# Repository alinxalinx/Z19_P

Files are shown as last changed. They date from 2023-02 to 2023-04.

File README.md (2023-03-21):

# Xilinx Zynq Ultrascale+ MPSoC Series Development Board Z19_P
## Introduction to Development Board
The entire structure of the development board is designed based on our consistent core board+extension board pattern. Core board and expansion board
High speed inter board connectors are used for connection.
The core board is mainly composed of a minimum system of ZU19EG+9 DDR4+eMMC+2 QSPI FLASH.
The main chip is a Zynq UltraScale+MPSoCs series chip from Xilinx Company, with a model of
XCZU19EG-2FFVC1760I。 The ZU19EG chip can be divided into processor system (PS) and
Programmable Logic (PL). Five DDR4, PL chips are attached to the PS end of the ZU19EG chip
Four DDR4 chips are attached to the terminal, each with a capacity of up to 1G bytes, enabling the ARM system and FPGA system to work independently
The function of managing and storing data. PS side 8GB eMMC FLASH memory chip and two 512Mb QSPI FLASH chips
The operating system, file system, and user data used to statically store MPSoCs.
The backplane extends a variety of peripheral interfaces for the core board, including 2-way FMC_ HPC, 1-way M.2 SSD interface, 1
Road mini_ DP interface, 1 USB 3.0 OTG interface, 1 Gigabit Ethernet interface, 2 UART interfaces, 1 PCIEX16 interface
Gold finger and some key LEDs
## Key Features
1. 9 micro DDR4 chips, 5 PS chips, 4 PL chips, capacity 512Mx16bit, model MT40A512M16LY-062E
2. Two Quad-SPI FLASH chips with a capacity of 512Mbit and a model of MT25QU512ABB1EW9-0SIT
3. One eMMC FLASH chip, size 32G bytes, model MTFC32GAPALBH-IT
4. Eight high-speed expansion ports, using eight 120pin board connectors. The core board connector model is AXK5A2137YG, and the backplane connector model is AXK6A2337YG
5. One PCIe 3.0x16 interface
6. 1-way M.2 interface, PCIEx1 (ps), speed 6Gbps
7. 1-channel DP output interface, mini DP (ps), maximum support 4kx2k@30fps output
8. 1-way USB 3.0 interface, USB (ps), speed 5.0Gbps, flat USB interface (USB Type A)
9. 1-way Gigabit Ethernet interface, jl2121, connected to the ps terminal, rgmii interface
10. Two uart to usb interfaces, one connected to the PS terminal and one connected to the PL terminal
11. 1 Micro SD card holder (ps)
12. Two FMC HPC expansion ports
13. EEPROM and temperature sensor, one EEROM 4Kbit (2x256x8bit) (ps), one LM75 temperature chip (ps), with an accuracy of 0.5 degrees
14. Four LED lights, one Done indicator light, one power supply, one PL control, and one PS control
15. One 4-digit dial switch, and the board supports four modes of startup
16. Size 225.82mm x 106.65mm
17. Power supply 12v/3A
# Z19_P Demo Project
## Description
This is vivado factory demo project for ALINX board.
## Requirement
* Vivado 2020.1
* Z19_P Development Board
## Create Vivado Project
* Download recent release ZIP archive.
* Create new project folder.
* Extract the download ZIP to the new project folder.

There are two methods to create vivado project as below:
### Create Vivado Project in Vivado tcl console
1. Open Vivado software and switch to "**auto_create_project**" path with **cd** command and **Enter**
```
cd \<archive extracted location\>/vivado/auto_create_project
```
2. Type **source ./create_project.tcl** and **Enter**
```
source ./create_project.tcl
```

### Create Vivado Project using bat
1. In "**auto_create_project**" folder, there is "**create_project.bat**", open it in edit mode, and change to your own vivado software installation path. Save and close.
```
CALL E:\XilinxVitis\Vivado\2020.1\bin\vivado.bat -mode batch -source create_project.tcl
PAUSE
```
2. Double click bat file in Windows environment

For more information, please post on the [ALINX Website] (https://www.alinx.com/en).

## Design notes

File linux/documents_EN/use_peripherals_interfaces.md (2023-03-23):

[Back to Home](../)
## Use the interfaces and peripherals on the development board in LINUX
---
-These interfaces and peripherals are available on the Z19-P development boards :\
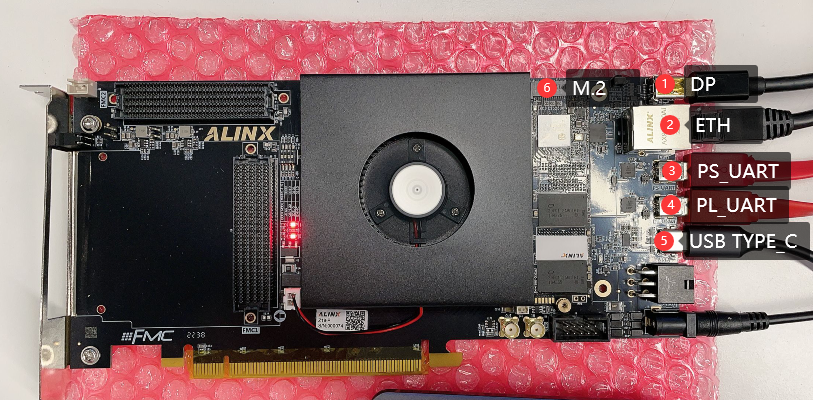
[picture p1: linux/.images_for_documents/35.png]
\
①DP\
②ETH\
③PS_UART\
④PL_UART\
⑤USB TYPE-C\
⑥M.2
⑦EMMC(图中不可见)\
⑧EEPROM(图中不可见)\
⑨QSPI FLASH(图中不可见)\
⑩RTC(图中不可见)\
⑪LM75(图中不可见)\
PS : In the Linux system on the development board created earlier, I integrated some scripts in Path *~/shells_for_testing_peripheral_devices/* to test these interfaces and peripherals. You can also refer to these scripts to use these interfaces and peripherals :\
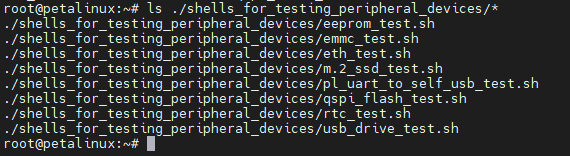
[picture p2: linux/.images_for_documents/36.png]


---
### ①DP
#### 1.1What is DP
DP (DisplayPort) interface is a digital video and audio interface standard used to connect computers, televisions, monitors, audio and other equipment. It is an open standard developed by Video Electronics Standards Association (VESA).\
There are two physical interfaces of DP interface, one is the standard DP interface in rectangular shape, and the other is the Mini DP interface in circular shape. The Mini DP interface is used on our development board.
#### 1.2Using DP in Linux
Connect DP to the display, and you can see the desktop of Macthbox after the system is started :\
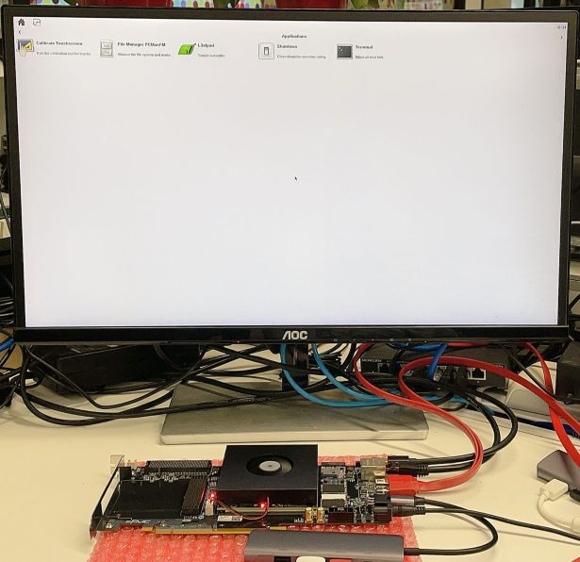
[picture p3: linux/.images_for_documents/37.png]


---
### ②ETH
#### 2.1What is ETH
In the Linux operating system, \"ETH\" usually refers to the network interface device, which is the hardware device used to communicate between the computer and the network. In Linux, you can use the *ifconfig* command to manage and configure network interface devices. The development board and other network devices can be connected in the same network through the ETH interface for data transmission.\
In the Ethernet protocol, each device is assigned a unique MAC address for identification and communication in the network. When computers send data through network interface devices, they will be encapsulated in Ethernet frames and routed and transmitted using MAC addresses.
#### 2.2Using ETH in Linux
Connect ETH (such as through router or switch) to LAN :\
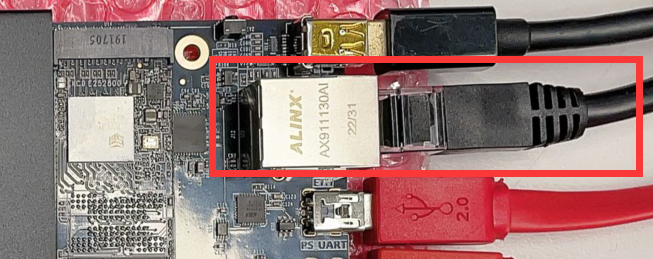
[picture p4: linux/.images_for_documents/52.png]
\
Then power on the development board, log in to the system, and use *ifconfig* to view the current ETH status :\
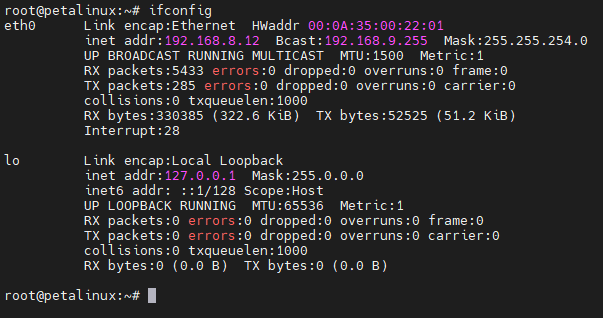
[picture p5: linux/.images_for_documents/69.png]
\
If your router or switch supports DHCP, both eth0 and eth1 will be automatically connected and be assigned an IP address.\
If no IP address is assigned, you need to use the following command to assign it manually, for example :\
`ifconfig eth0 192.168.8.67`\
The *ifconfig* command can also be used to set the subnet mask; If the MAC address needs to be modified, */etc/network/interfaces* needs to be modified; If you want to set the gateway, you need to use command **route**; If you need to modify DNS, you need to modify */etc/resolv.conf*. The relevant configuration will not be detailed, generally, as long as you connect to the LAN through the network cable, you can use eth0 directly after the system is powered on.\
#### 2.3Use the built-in script to set up and test ETH
Run the *eth_test.sh*  script in *~/shells_for_testing_peripheral_devices/*. This script can be followed by a parameter, that is, the address you want to ping. For example, here I ping www.baidu.com. If no parameter is added, the default is ping *www.google.com* :\
\
Finally, the result of the ping and the speed of the network interface link will be print.

---
### ③PS_UART
#### 3.1What is PS_UART
UART is a communication protocol, which is called "Universal Asynchronous Receiver/Transmitter". It is a serial communication protocol that can be used to transmit data between microcontrollers, sensors, computer peripheral devices, communication devices, etc.\
UART uses two signal lines for data transmission: one is the data line (TX), which is responsible for sending data; The other is the receiving line (RX), which is responsible for receiving data. UART communication uses asynchronous transmission mode, that is, the clock signals of both sides of the communication are not synchronized, and the start bit, stop bit and parity bit need to be added in the data transmission to ensure the correctness of the data.\
The main advantages of UART are simple, flexible and widely used. Because it is a general protocol that can communicate between different devices, it is widely used in embedded systems and communication fields.\
PS_ UART is the UART interface of ARM end (also called PS end) in ZYNQMP chip.
#### 3.2Using PS_UART in Linux
PS_UART is used as the default terminal console for Linux in our system. Connect PS_UART to the PC(***The driver of CP210x needs to be installed on the PC***) :\
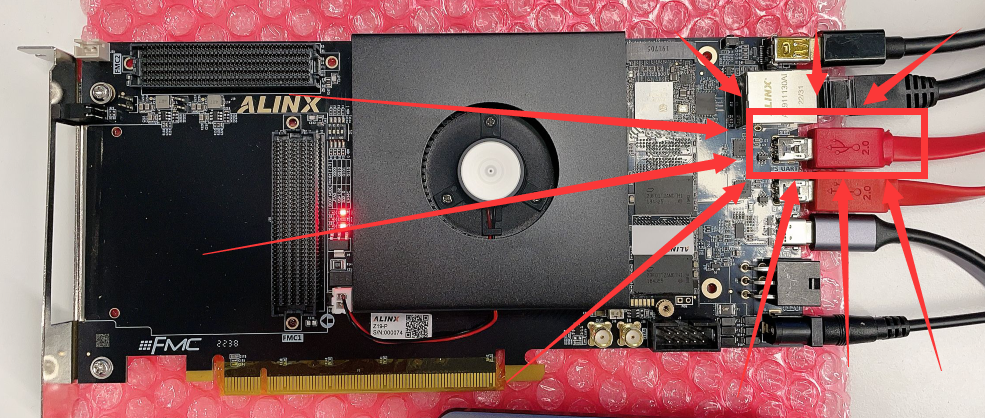
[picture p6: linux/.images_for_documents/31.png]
\
Open the corresponding COM with the serial port tool, set the baud rate to 115200, close the flow control, and click the OK button :\
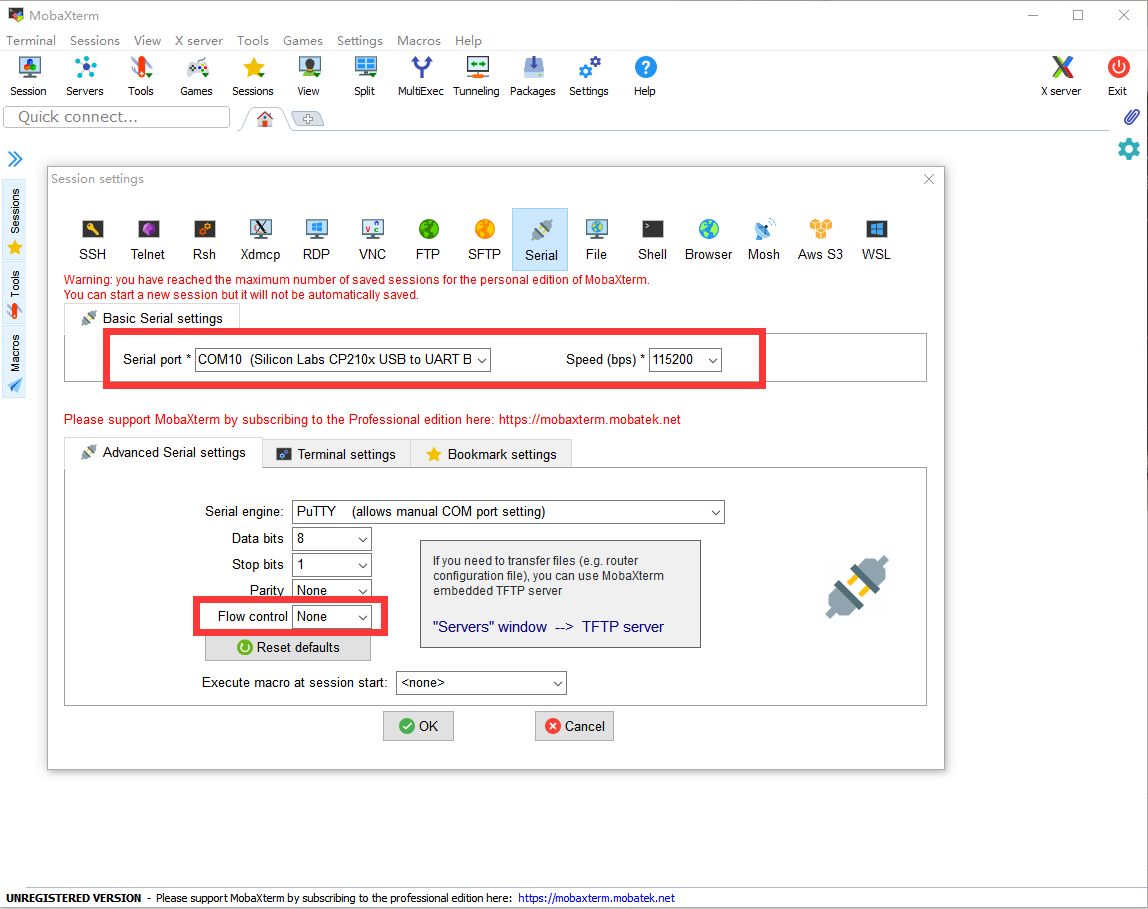
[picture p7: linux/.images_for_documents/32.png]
\
After starting the development board, you can see the print information in the serial port tool :\
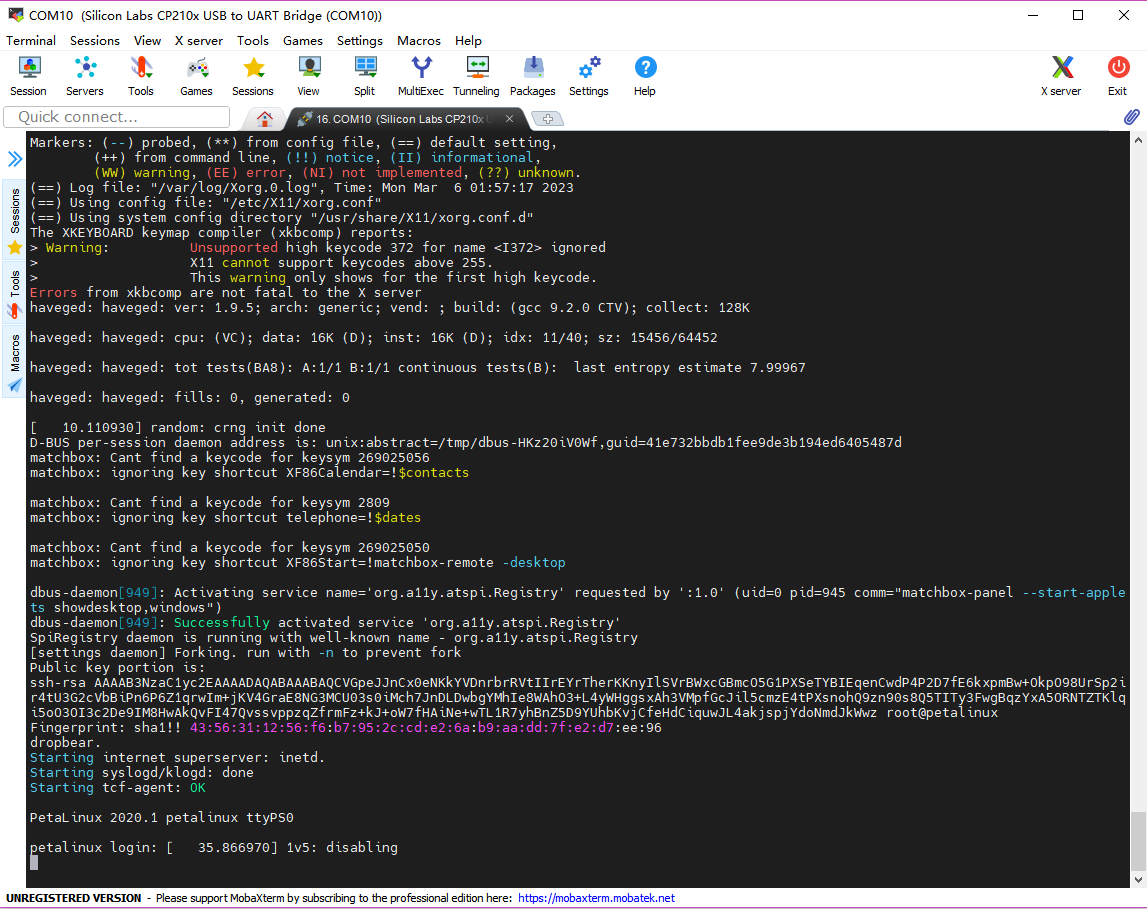
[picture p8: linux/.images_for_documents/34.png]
\
The device of PS_UART in our Linux system is */dev/ttyPS0*. You can use PS_UART interface transmits data by using the `echo "PS_UART test" > /dev/ttyPS0` command :\
\
You can see that the serial port has echo. But PS_UART is used for terminal console, so it is not recommended to operate */dev/ttyPS0*.

---
### ④PL_UART
#### 4.1What isPL_UART
PL_UART is different from PS_UART is the UART interface of the FPGA (also called PL) in the ZYNQMP chip.
#### 4.2Using PL_UART in Linux
Connect the PL_UART to the PC(***The driver of CP210x needs to be installed on the PC*** ).\
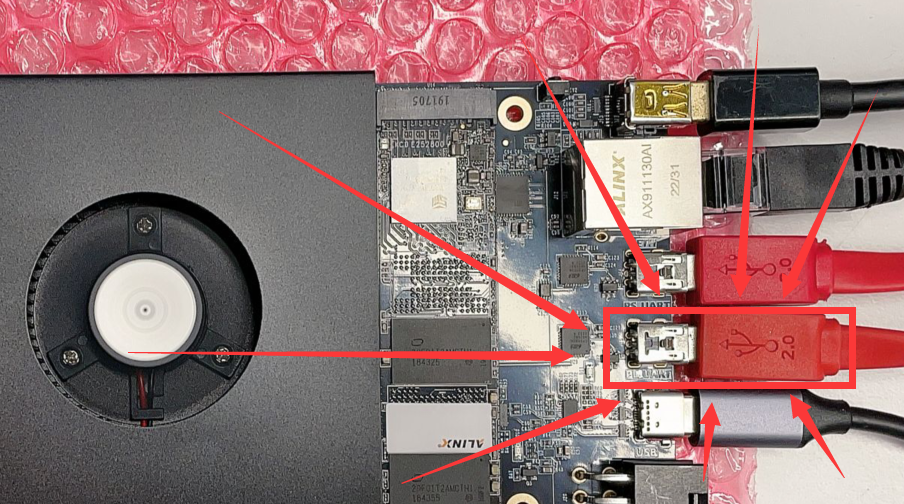
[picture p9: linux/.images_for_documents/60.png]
\
Open the serial port tool, select the corresponding COM, and set the baud rate to 115200 :\
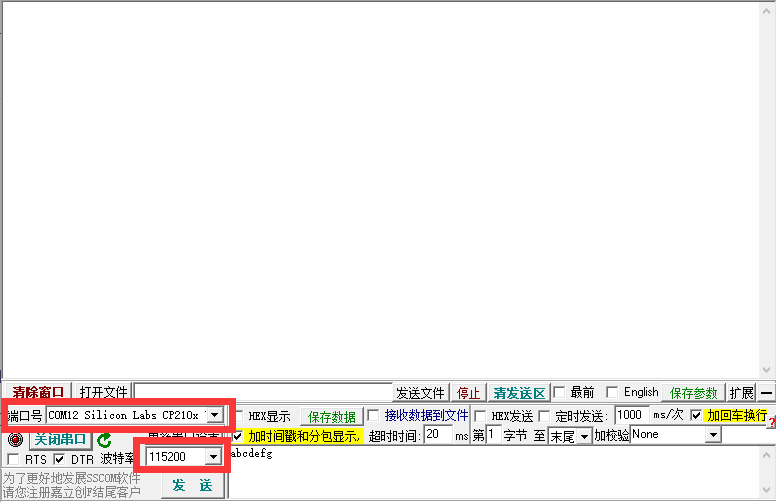
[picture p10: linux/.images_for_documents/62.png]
\
**The number of COM depends on your PC. If your PS_UART and PL_UART are all connected to PC, you can see at least two COM suffixes with *Silicon Labs CP210x USB to UART Bridge* :**\
\
In the Linux system of the development board, the PL_UART device is */dev/ttyPS3*, and the default baud rate is 9600. You can use this command to set the baud rate.\
`stty -F /dev/ttyPS3 ispeed 115200 ospeed 115200 cs8`\
We set it to 115200 corresponding to the setting of the serial port tool, and then use the following command to print the data received by UART :\
`cat /dev/ttyPS3`\
\
Then send some data in the serial port tool, and you can see that the system has received these data :\
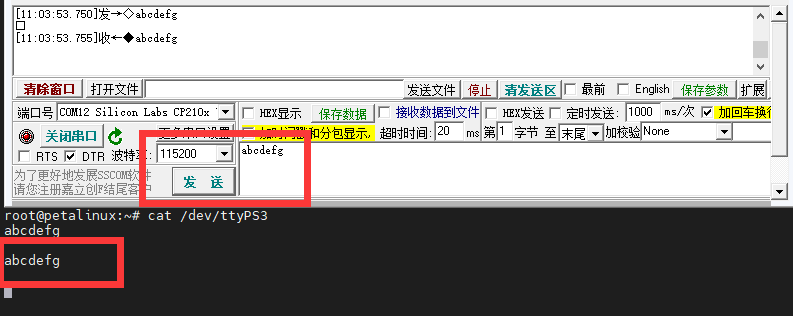
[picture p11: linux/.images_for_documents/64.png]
\
Press *ctrl c* on the keyboard to exit the *cat /dev/ttyPS3* command, and then use the following command to send data \"*PL_UART test*\" to the PC through PL_UART. The serial port tool can receive data:\
`echo "PL_UART test" > /dev/ttyPS3`\
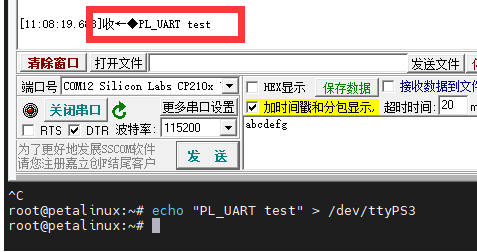
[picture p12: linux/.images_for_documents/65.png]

#### 4.3Use the built-in script in Linux to test PL_UART
Connect the PL_UART to any USB port on the development board :\
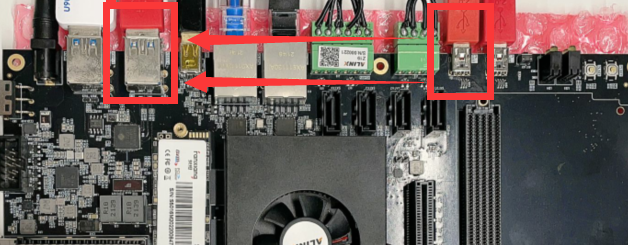
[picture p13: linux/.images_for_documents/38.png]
\
Run the *pl_uart_to_self_usb_test.sh*  script in *~/shells_for_testing_peripheral_devices/* :\
\
Output \"*pl uart to self usb test OK* \" indicates that the UART is intact(ps: this script also verifies that the USB interface is intact).

---
### ⑤USB TYPE-C
#### 5.1What is USB
USB is the abbreviation of Universal Serial Bus. It is a universal data transmission standard used to connect computers or other devices with other devices, including printers, keyboards, mice, scanners, digital cameras, mobile devices and other external devices.\
With the continuous development of technology, the version of USB is also constantly updated. USB 1.0 is the earliest version and the transmission speed is very slow, but with the introduction of USB 2.0, the transmission speed has been significantly improved. USB 3.0 and USB 3.1 are faster versions, providing higher transmission speed and more power. At the same time, USB can also support different data transmission protocols, including HID (human interface device), audio, video and storage devices.\
Our development board has a USB TYPE-C interface that can be connected to a HUB with a TYPE-C interface. Of course, it also connects to other TYPE-C interface devices.\

#### 5.2Using USB on Linux systems
In fact, common USB devices can be used directly on this system. For example, the mouse and keyboard can be used directly with the desktop. If you use the storage tools such as USB flash disk, you need to pay attention to the partition and file system format. You can refer to the partition and format method of SSD in **⑥M.2**. After the USB flash disk is connected to the system, the device operation files are generally */dev/sda1*, */dev/sda2*, etc.
#### 5.3Use the built-in script in Linux to test USB Drive
Run the *usb_drive_test.sh*  script in *~/shells_for_testing_peripheral_devices/* ( *ps：This system does not support the NTFS file system, so the USB flash drive of the NTFS partition cannot be used directly* ) :\


---
### ⑥M.2
#### 6.1What is M.2
M.2 is a high-speed, low-power interface for connecting external devices, such as solid-state hard disk, NVMe devices, etc.\
M.2 Interface consists of PCI Express (PCIe) and SATA (Serial ATA) protocols, which can be used for data transmission, storage and communication. PCIe protocol provides faster transmission speed and more bandwidth, while SATA protocol is more suitable for low-power and high-capacity storage devices.
#### 6.2Use M.2 interface in the system
Take SSD equipment as an example, connect SSD on the M.2 interface of the development board (please do not operate with power) :\
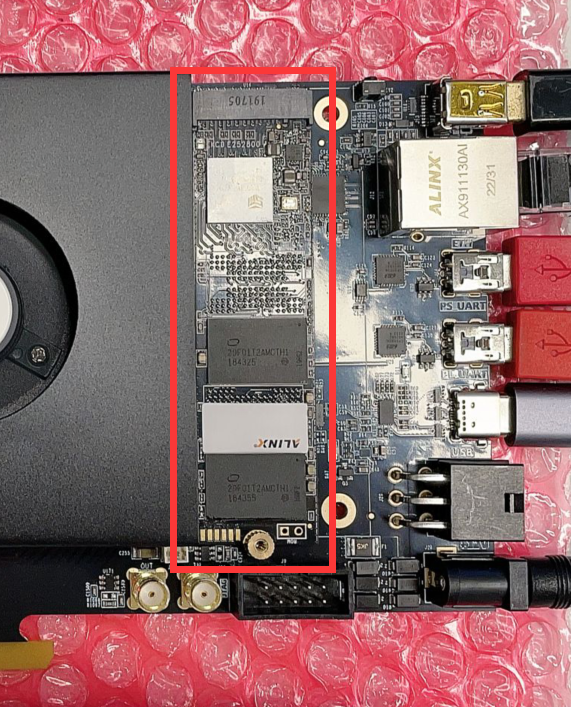
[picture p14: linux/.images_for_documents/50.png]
\
Then start the development board and log in to Linux. If you can find */dev/nvme0n1*, it means that the SSD has been successfully recognized.\
If this SSD has been partitioned, you can also find the device operation files corresponding to partitions like */dev/nvme0n1p1*, */dev/nvme0n1p2* and so on.\
If the SSD does not have a partition or the file system format of the partition is not supported by the Linux system, you can use the **fdisk** tool to allocate the partition, use the **mkfs** tool to set the file system formart, and use the **mount** command to mount it.
For example, the following command will delete the first partition of  */dev/nvme0n1*  and create a new partition, then format the partition into ext4 and mount it to */run/media/nvme0n1p1* :\
```
#Unmount partition
umount /dev/nvme0n1p1
#Delete a partition of /dev/nvme0n1 and create a new partition
echo "d

n
p
1

w
" | fdisk /dev/nvme0n1
#Format the /dev/nvme0n1p1 partition into ext4
echo "y

" | mkfs.ext4 /dev/nvme0n1p1
#mount /dev/nvme0n1p1 on /run/media/nvme0n1p1
mount /dev/nvme0n1p1 /run/media/nvme0n1p1
```
After mounting, you can operate on files in the mounted path, and these files will eventually be saved in the SSD.
#### 6.3Use the built-in script in Linux to test M.2 SSD
Run the *m.2_ssd_test.sh*  script in *~/shells_for_testing_peripheral_devices/* :\
\
Different information will be printed according to the usage of your SSD, but as long as the M.2 interface and SSD are intact, \"*ssd read write OK* \" will be output.

---
### ⑦EMMC
#### 7.1What is EMMC
EMMC (Embedded MultiMediaCard) is a storage device widely used by embedded devices. It integrates flash memory chip, controller, host interface and flash memory management software into a small package. With its small size, low power consumption and high cost performance, eMMC is a common choice in embedded device storage solutions.\
EMMC is mainly used in mobile devices (such as smart phones, tablets, digital cameras, etc.) and embedded devices in automotive, industrial control and other fields. It provides a high-speed and reliable storage solution, supports fast startup and data reading and writing, and can store operating system, application programs, media files and other data.\
An 8G EMMC is integrated on our development board.
#### 7.2Using EMMC on Linux
The operation file of EMMC in Linux system is */dev/mmcblk0*. The use method is similar to that of SSD in **⑧M.2** : set the partition, format the partition, and finally mount the partition. for example :
```
#Unmount partition
umount /dev/mmcblk0p1
#Delete a partition of /dev/mmcblk0 and create a new partition
echo "d

n
p
1

w
" | fdisk /dev/mmcblk0
#Format the /dev/mmcblk0p1 partition into ext4 format
echo "y

" | mkfs.ext4 /dev/mmcblk0p1
#mount /dev/mmcblk0p1 on /media/sd-mmcblk0p1
mount /dev/mmcblk0p1 /media/sd-mmcblk0p1
```
After mounting, you can operate on files in the mounted path, and these files will eventually be saved in EMMC.
#### 7.3Use the built-in script in Linux to test EMMC
Run the *emmc_test.sh* script in *~/shells_for_testing_peripheral_devices/*  :\


---
### ⑧EEPROM
#### 8.1What is EEPROM
EEPROM is a non-volatile memory (NVM), which is an improved version of the electrically erasable programmable read-only memory (EPROM). EEPROM can be erased and programmed by electronic signals.\
EEPROM is usually used to store a small amount of data, such as configuration information on the chip, product serial number, encryption key, etc. In some electronic devices, EEPROM can also be used to store user settings and personal data.\
Compared with flash memory, EEPROM has faster reading speed and higher durability, but smaller capacity. Compared with DRAM, EEPROM has longer data retention time, but slower write speed.
#### 8.2Using EEPROM on Linux
The operating file of eeprom in the system is */sys/bus/i2c/devices/1-0050/eeprom*.\
Use the following command to write data to eeprom :\
`echo -e "test e2prom\n" > /sys/bus/i2c/devices/1-0050/eeprom`\
Use the following command to view the contents of eeprom :\
`cat /sys/bus/i2c/devices/1-0050/eeprom`\

#### 8.3Use the built-in script in Linux to test EEPROM
Run the *eeprom_test.sh* script in *~/shells_for_testing_peripheral_devices/*  :\


---
### ⑨QSPI FLASH
#### 9.1What is QSPI FLASH
Flash is a kind of high-speed flash memory, which is often used in embedded systems and other applications to store program code, configuration data and other information.\
QSPI Flash is a flash chip based on SPI interface. It communicates through four parallel data lines (quad interfaces). Compared with traditional SPI Flash, it can achieve faster data transmission speed, usually up to tens of MHz. The capacity of QSPI Flash is usually between a few megabytes and tens of megabytes.\
QSPI Flash has many advantages, including fast read and write speed, low power consumption, erasability, easy integration and use, etc. In addition, it can be programmed and erased by software without any external equipment or signal line.
#### 9.2Using QSPI FLASH on Linux systems
In the current Linux system, QSPI FLASH is used to store the environment variables of u-boot. If you modify the environment variables of u-boot, you need to be careful when operating QSPI FLASH.
The operation file of QSPI FLASH in the system is */dev/mtd0*.
The FLASH device needs to be erased before writing. Use the following command to erase the first sector of QSPI FLASH :\
`flash_erase /dev/mtd0 0 1`\
*/dev/mtd0* is a block device. You can use the **dd** command to read or write files to */dev/mtd0*.\
Write the file to */dev/mtd0 with the following command* :
```
touch /home/root/.qspiflashwrite
echo "qspiflash test" > /home/root/.qspiflashwrite
dd of=/dev/mtd0 if=/home/root/.qspiflashwrite bs=4096 count=1
```
Use the following command to read data from */dev/mtd0* to a file :
```
touch /home/root/.qspiflashread
dd if=/dev/mtd0 of=/home/root/.qspiflashread  bs=4096 count=1
```
#### 9.3Use the built-in script in Linux to test QSPI FLASH
Run the *qspi_flash_test.sh* script in *~/shells_for_testing_peripheral_devices/*  :\


---
### ⑩RTC
#### 10.1What is RTC
The Real Time Clock (RTC) unit provides an accurate time reference for the entire system and application software.
#### 10.2Using RTC on Linux systems
In our Linux system, the device operation file of RTC is */dev/rtc0*. You can use the **hwclock** command to read and write */dev/rtc0*. For example:
```
#Set the system time to "2023-03-01 10:30:00"
date --set="2023-03-01 10:30:00"
#Write the system time to/dev/rtc0
hwclock -f /dev/rtc0 -w
#Update the system time with the time in /dev/rtc0
hwclock -f /dev/rtc0 -r
```

#### 10.3Use the built-in script in Linux to test RTC
Run the *ds1308_test.sh* script in *~/shells_for_testing_peripheral_devices/* :\


---
### ⑪LM75
#### 11.1What is LM75
LM75 is a digital temperature sensor chip produced by Texas Instruments. It can measure the ambient temperature and communicate with other devices through I2C bus. It is a digital temperature sensor chip with stable performance, high accuracy and good reliability.
#### 11.2Using LM75 on Linux systems
The temperature value collected by LM75 can be obtained by directly reading */sys/bus/i2c/devices/1-0048/hwmon/hwmon0/temp1_input* in Linux, **the unit of this data is m°C**:\
`cat /sys/bus/i2c/devices/1-0048/hwmon/hwmon0/temp1_input`\
\
The temperature read here is 30625m°C, equal to 30.625°C.

---
---
- Visit [ALINX official website](https://www.alinx.com) for more information.

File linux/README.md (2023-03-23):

# Run Linux on Development Boards Z19-P / 在开发板Z19-P上使用Linux
---
---
## Content in this path / 本路径中的内容 
	│
	└─── linux
		│
		├── hardware
		│	│
		│	└──── Z19-P
		│		│	
		│	 	└─ design_1_wrapper.xsa	
		│
		├── petalinux
		│
		├── documents_EN
		│	│
		│	├──  make_sd_for_runnging_linux.md	
		│	│
		│	├──  use_petalinux_to_make_linux.md	
		│	│
		│	└──  use_peripherals_interfaces.md
		│
		├── documents_CN
		│	│
		│	├──  make_sd_for_runnging_linux.md	
		│	│
		│	├──  use_petalinux_to_make_linux.md
		│	│
		│	└──  use_peripherals_interfaces.md
		│
		├── auto_config_petalinux_hardware.sh
		│
		├── set_offline_sstate_and_downloads.sh
		│
		└── README.md
---
---
## Documentation Guidelines
- If you want to quickly start a Linux on the development board, please refer to [make_sd_for_runnging_linux.md](./documents_EN/make_sd_for_runnging_linux.md).
- If you want to use Petalinux tool to configure the petalinux project we provide, please refer to [use_petalinux_to_make_linux.md](./documents_EN/use_petalinux_to_make_linux.md).
- If you have successfully started Linux on the development board, and now want to know what interfaces are on the development board and how to use them, please refer to [use_peripherals_interfaces.md](./documents_EN/use_peripherals_interfaces.md).
## 文档指引
- 如果你想快速在开发板上启动Linux，请参考[make_sd_for_runnging_linux.md](./documents_CN/make_sd_for_runnging_linux.md)。
- 如果你想用Petalinux工具来配置我们提供的petalinux工程，请参考[use_petalinux_to_make_linux.md](./documents_CN/use_petalinux_to_make_linux.md)。
- 如果你已经成功在开发板上启动了Linux，现在想知道开发板上有哪些接口以及如何使用，请参考[use_peripherals_interfaces.md](./documents_CN/use_peripherals_interfaces.md)。
---
---
- Visit [ALINX Official Website](https://www.alinx.com) for more information.
- 访问[ALINX官方网站](https://www.alinx.com)以获取更多信息。

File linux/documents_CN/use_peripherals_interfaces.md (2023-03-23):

[返回首页](../)
## 在LINUX中使用开发板上的接口和外设

---
- Z19-P开发板上有这些接口和外设：\
\
①DP\
②ETH\
③PS_UART\
④PL_UART\
⑤USB TYPE-C\
⑥M.2
⑦EMMC(图中不可见)\
⑧EEPROM(图中不可见)\
⑨QSPI FLASH(图中不可见)\
⑩RTC(图中不可见)\
⑪LM75(图中不可见)\
PS：在前面制作的开发板上的Linux系统中，我集成了一些脚本在 *~/shells_for_testing_peripheral_devices/* 路径中用于测试这些接口和外设，你也可以参考这些脚本来使用这些接口和外设：\


---
### ①DP
#### 1.1什么是DP
DP (DisplayPort) 接口是一种数字视频和音频接口标准，用于连接计算机、电视、显示器、音响等设备。它是一种开放标准，由 Video Electronics Standards Association (VESA) 组织制定。\
DP 接口的物理接口有两种，一种是矩形形状的标准 DP 接口，另一种是圆形形状的 Mini DP 接口。我们的开发板上使用的就是Mini DP接口。
#### 1.2在Linux中使用DP
把DP连接到显示器上即可，系统启动后可以看到Macthbox的桌面：\


---
### ②ETH
#### 2.1什么是ETH
在Linux操作系统中，\"ETH\" 通常指的是网络接口设备，它是用于在计算机与网络之间进行通信的硬件设备。在Linux中，可以使用 *ifconfig* 命令来管理和配置网络接口设备。可以通过ETH接口把开发板和其他网络设备连接在同一网络中，以便进行数据传输。\
在以太网协议中，每个设备都被分配一个唯一的MAC地址，以便在网络中进行识别和通信。当计算机通过网络接口设备发送数据时，它们将被封装在以太网帧中，并使用MAC地址进行路由和传输。
#### 2.2在Linux中使用ETH
连接ETH(比如通过路由器或交换机)到局域网：\
\
然后开发板上电，登陆系统，使用 *ifconfig* 可以查看当前ETH的状态：\
\
如果你的路由器或交换机支持DHCP，eth0和eth1都会自动连接并分配到ip。\
如果没有被分配ip则需要用下面的命令来手动分配，例如：\
`ifconfig eth0 192.168.8.67`\
*ifconfig* 命令还可以用来设置子网掩码；如果需要修改MAC地址则需要修改 */etc/network/interfaces* ；如果要设置网关则需要用到**route**命令；如果需要修改DNS则需要修改 */etc/resolv.conf* ，相关的配置就不详细讲了，一般来说只要通过网线连接到局域网，系统上电之后就可以直接使用eth0了。
#### 2.3使用系统内置的脚本设置并测试ETH
运行 *~/shells_for_testing_peripheral_devices/* 中的 *eth_test.sh* 脚本，这个脚本后可以带一个参数，即你想ping的地址，比如这里我ping了一下百度，如果不加参数则默认ping *www.google.com* ：\
\
最后会显示ping的结果和网口link的速度。

---
### ③PS_UART
#### 3.1什么是PS_UART
UART是一种通信协议，全称为“通用异步收发传输器”（Universal Asynchronous Receiver/Transmitter）。它是一种串行通信协议，可以用于在微控制器、传感器、电脑周边设备、通信设备等之间传输数据。\
UART使用两根信号线来进行数据传输：一根是数据线（TX），负责发送数据；另一根是接收线（RX），负责接收数据。UART通信使用异步传输方式，也就是说，通信双方的时钟信号不同步，需要在数据传输中加入起始位、停止位和奇偶校验位来保证数据的正确性。\
UART的主要优点是简单、灵活和广泛使用。由于它是一种通用协议，可以在各种不同的设备之间进行通信，因此在嵌入式系统和通信领域中应用广泛。\
PS_UART是ZYNQMP芯片中ARM端(也叫做PS端)的UART接口。
#### 3.2在Linux中使用PS_UART
PS_UART在我们制作的系统中用于Linux的默认终端窗口，把PS_UART连接到PC(***PC上需要安装CP210x的驱动***)：\
\
用串口工具打开对应的COM，设置波特率设置为115200，关闭流控制，点击OK按钮：\
\
启动开发板后可以看到串口工具中打印信息：\
\
PS_UART在我们制作的Linux系统中的设备是 */dev/ttyPS0* ，使用`echo "PS_UART test" > /dev/ttyPS0`命令可以通过PS_UART接口传输数据：\
\
可以看到串口有回显，但是PS_UART被用于终端窗口，因此不建议对 */dev/ttyPS0* 进行操作。

---
### ④PL_UART
#### 4.1什么是PL_UART
PL_UART区别于PS_UART，是ZYNQMP芯片中FPGA端(也叫做PL端)的UART接口。
#### 4.2在Linux中使用PL_UART
把PL_UART连接到PC(***PC上需要安装CP210x的驱动***)：\
\
打开串口工具，选择对应COM，波特率设置为115200：\
\
**COM的编号取决于你的PC，如果此时你的PS_UART和PL_UART都接在PC上，那么至少能看到两个后缀是*Silicon Labs CP210x USB to UART Bridge* 的COM：**\
\
在开发板的Linux系统中PL_UART设备是 */dev/ttyPS1*，默认波特率是9600，可以用这个命令来设置波特率：\
`stty -F /dev/ttyPS1 ispeed 115200 ospeed 115200 cs8`\
我们把它设置成115200和串口工具的设置对应，然后使用命令：\
`cat /dev/ttyPS1`\
来显示PL_UART收到的数据：\
\
在串口工具中发送一些数据，可以看到系统中收到了这些数据：\
\
在键盘上按*ctrl c*退出*cat /dev/ttyPS1*命令，然后用命令：\
`echo "PL_UART test" > /dev/ttyPS1`\
通过PL_UART发送数据*PL_UART test* 到PC，PC上串口工具可以收到数据：\

#### 4.3使用系统内置的脚本测试PL_UART
把PL_UART连接到USB HUB上：\
\
运行 *~/shells_for_testing_peripheral_devices/* 中的 *pl_uart_to_self_usb_test.sh* 脚本：\
\
输出\"*pl uart to self usb test OK* \"说明PL_UART完好(ps：这个脚本同时也验证了USB接口完好)。

---
### ⑤USB TYPE-C
#### 5.1什么是USB
USB是Universal Serial Bus的缩写，它是一种通用的数据传输标准，用于将计算机或其他设备与其他设备连接，包括打印机、键盘、鼠标、扫描仪、数字相机、移动设备和其他各种外部设备。\
随着技术的不断发展，USB的版本也在不断更新。USB 1.0是最早的版本，传输速度很慢，但是随着USB 2.0的推出，传输速度得到了显著提高。USB 3.0和USB 3.1是更快的版本，提供更高的传输速度和更多的功率。同时，USB还可以支持不同的数据传输协议，包括HID（人体接口设备）、音频、视频和存储设备等。\
我们的开发板上有一个USB TYPE-C接口，可以接入TYPE-C接口的HUB。\

#### 5.2在Linux系统上使用USB
实际上常用USB设备都可以直接在这个系统上使用。比如鼠标键盘，都可以直接配合桌面来使用。使用U盘这些存储工具的话则需要注意分区和文件系统格式，可以参考**⑥M.2**中SSD的分区和格式化方法。U盘接入到系统之后，设备操作文件一般是 */dev/sda1* 、  */dev/sda2* 等等。
#### 5.3使用系统内置的脚本测试U盘
使用 *~/shells_for_testing_peripheral_devices/* 中的 *usb_drive_test.sh* 脚本( *ps：这个系统是不支持NTFS文件系统的，所以NTFS分区的U盘无法直接使用* )：\


---
### ⑥M.2
#### 6.1什么是M.2
M.2是一种高速、低功耗的接口，用于连接外部设备，如固态硬盘、NVMe设备等等。\
M.2接口由PCI Express（PCIe）和SATA（串行ATA）两种协议组成，可用于数据传输、存储和通信。PCIe协议提供了更快的传输速度和更多的带宽，而SATA协议则更适合于低功耗和高容量的存储设备。
#### 6.2在系统中使用M.2接口
以SSD设备为例，在开发板的M.2接口上接上SSD(请不要带电操作)：\
\
然后启动开发板，登录Linux，如果能找到 */dev/nvme0n1* 说明SSD已经成功被识别到了。\
如果这个SSD已经被分过区了，那么还能找到 */dev/nvme0n1p1*, */dev/nvme0n1p2* 等分区对应的设备操作文件。\
如果SSD没有分区或者分区的文件系统格式Linux系统不支持，可以使用**fdisk**工具来分配分区，使用**mkfs**命令制作文件系统以及使用mount命令挂载。\
例如下面的命令将会删除 */dev/nvme0n1* 的第一个分区并新建一个分区，再把这个分格式化成ext4并挂载到 */run/media/nvme0n1p1* ：
```
#解挂分区
umount /dev/nvme0n1p1
#删除/dev/nvme0n1的一个分区并新建一个分区
echo "d

n
p
1

w
" | fdisk /dev/nvme0n1
#把/dev/nvme0n1p1分区格式化成ext4格式
echo "y

" | mkfs.ext4 /dev/nvme0n1p1
#挂载/dev/nvme0n1p1到/run/media/nvme0n1p1
mount /dev/nvme0n1p1 /run/media/nvme0n1p1
```
挂载之后，就可以在挂载的路径中操作文件了，而这些文件最终都会被保存在SSD中。
#### 6.3使用系统内置的脚本测试M.2 SSD
运行 *~/shells_for_testing_peripheral_devices/* 中的 *m.2_ssd_test.sh* 脚本：\
\
根据你的SSD的使用情况会用不同打印信息，但只要M.2接口和SSD是完好的最终肯定会输出\"*ssd read write OK* \"。

---
### ⑦EMMC
#### 7.1什么是EMMC
eMMC（Embedded MultiMediaCard）是一种被嵌入式设备广泛采用的存储器件，它将闪存芯片、控制器、主机接口和闪存管理软件集成在一个小型封装中。eMMC的体积小、功耗低、性价比高，是嵌入式设备存储方案中的一种常见选择。\
eMMC主要应用于移动设备（例如智能手机、平板电脑、数字相机等）以及汽车、工业控制等领域的嵌入式设备中。它提供了一种高速、可靠的存储解决方案，支持快速启动和数据读写，可以存储操作系统、应用程序、媒体文件等数据。\
在我们的开发板上集成了一个8G的EMMC。
#### 7.2在Linux系统上使用EMMC
EMMC在Linux系统中的操作文件是 */dev/mmcblk0* ，使用方法和**②M.2**中SSD的使用方法类似：设置分区并格式化分区最后挂载分区。例如：
```
#解挂分区
umount /dev/mmcblk0p1
#删除/dev/mmcblk0的一个分区并新建一个分区
echo "d

n
p
1

w
" | fdisk /dev/mmcblk0
#把/dev/mmcblk0p1分区格式化成ext4格式
echo "y

" | mkfs.ext4 /dev/mmcblk0p1
#挂载/dev/mmcblk0p1到/media/sd-mmcblk0p1
mount /dev/mmcblk0p1 /media/sd-mmcblk0p1
```
挂载之后，就可以在挂载的路径中操作文件了，而这些文件最终都会被保存在EMMC中。
#### 7.3使用系统内置的脚本测试EMMC
运行 *~/shells_for_testing_peripheral_devices/* 中的 *emmc_test.sh* 脚本：\


---
### ⑧EEPROM
#### 8.1什么是EEPROM
EEPROM是一种非易失性存储器（NVM），它是电可擦可编程只读存储器（EPROM）的改进版本。EEPROM可以通过电子信号进行擦除和编程。\
EEPROM通常用于存储小量的数据，例如芯片上的配置信息、产品序列号、加密密钥等。在一些电子设备中，EEPROM还可以用来存储用户设置和个人资料等数据。\
与闪存相比，EEPROM具有更快的读取速度和更高的耐用性，但容量较小。与DRAM相比，EEPROM具有更长的数据保持时间，但写入速度较慢。
#### 8.2在Linux系统上使用EEPROM
eeprom在系统中的操作文件是 */sys/bus/i2c/devices/0-0050/eeprom* 。\
使用命令：\
`echo -e "test e2prom\n" > /sys/bus/i2c/devices/0-0050/eeprom`\
可以往eeprom中写入引号中的数据。\
使用命令：\
`cat /sys/bus/i2c/devices/0-0050/eeprom`\
可以查看eeprom中的内容。\

#### 8.3使用系统内置的脚本测试EEPROM
运行 *~/shells_for_testing_peripheral_devices/* 中的 *eeprom_test.sh* 脚本：\


---
### ⑨QSPI FLASH
#### 9.1什么是QSPI FLASH
Flash是一种高速闪存存储器，常用于嵌入式系统和其他应用中，用于存储程序代码、配置数据和其他信息。\
QSPI Flash是一种基于SPI接口的闪存芯片，它通过四个并行数据线（quad interface）进行通信，与传统的SPI Flash相比，可以实现更快的数据传输速度，通常达到几十MHz的传输速度。QSPI Flash的容量通常在几兆字节到几十兆字节之间。\
QSPI Flash具有许多优点，包括快速读写速度、低功耗、可擦写性、易于集成和使用等。此外，它还可以通过软件进行编程和擦除，而无需任何外部设备或信号线。
#### 9.2在Linux系统上使用QSPI FLASH
在当前的Linux系统中QSPI FLASH被用于存储u-boot的环境变量，如果修改了u-boot的环境变量那么操作QSPI FLASH就需要小心了。\
QSPI FLASH在系统中的操作文件是 */dev/mtd0*。\
FLASH设备在写之前需要先擦，使用下面的命令可以擦除QSPI FLASH的第一个扇区：\
`flash_erase /dev/mtd0 0 1`\
*/dev/mtd0* 是块设备，可以用**dd**命令来读写文件到 */dev/mtd0*。\
用下面的命令写文件到 */dev/mtd0* ：
```
touch /home/root/.qspiflashwrite
echo "qspiflash test" > /home/root/.qspiflashwrite
dd of=/dev/mtd0 if=/home/root/.qspiflashwrite bs=4096 count=1
```
用下面的命令从 */dev/mtd0* 读取数据到文件：
```
touch /home/root/.qspiflashread
dd if=/dev/mtd0 of=/home/root/.qspiflashread  bs=4096 count=1
```
#### 9.3使用系统内置的脚本测试QSPI FLASH
运行 *~/shells_for_testing_peripheral_devices/* 中的 *qspi_flash_test.sh* 脚本：\


---
### ⑩RTC
#### 10.1什么是RTC
实时时钟(RTC)单元为整个系统和应用软件提供了一个精确的时间基准。
#### 10.2在Linux系统上使用RTC
在我们的Linux系统中，RTC的设备操作文件是 */dev/rtc0*。可以用**hwclock**命令来读写 */dev/rtc0*。例如：
```
#设置系统时间为"2023-03-01 10:30:00"
date --set="2023-03-01 10:30:00"
#把系统时间写入到/dev/rtc0
hwclock -f /dev/rtc0 -w
#用/dev/rtc0中的时间更新系统时间
hwclock -f /dev/rtc0 -r
```

#### 10.3使用系统内置的脚本测试RTC
运行 *~/shells_for_testing_peripheral_devices/* 中的 *ds1308_test.sh* 脚本：\


---
### ⑪LM75
#### 11.1什么是LM75
LM75是一种数字温度传感器芯片，由德州仪器（Texas Instruments）公司生产。它可以测量环境温度，并通过I2C总线与其他设备进行通信。是一个性能稳定、精度高、可靠性好的数字温度传感器芯片。
#### 11.2在Linux系统上使用LM75
在Linux中直接读取 */sys/bus/i2c/devices/0-0048/hwmon/hwmon0/temp1_input* 就可以获取到LM75采集的温度值，**单位是m°C**：\
`cat /sys/bus/i2c/devices/0-0048/hwmon/hwmon0/temp1_input`\
\
这里读到的温度是30625m°C，也就是30.625°C。

---
---
- 访问[ALINX官方网站](https://www.alinx.com)以获取更多信息。

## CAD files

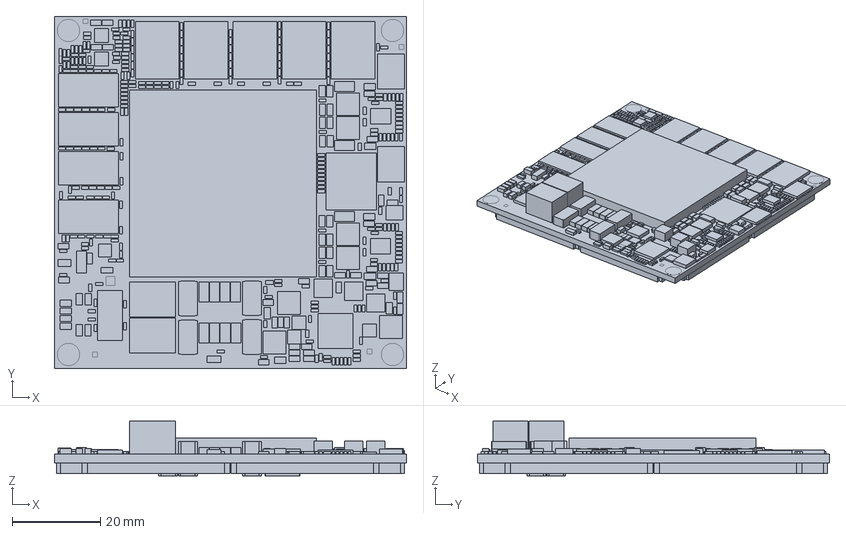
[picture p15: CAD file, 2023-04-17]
hardware/STEP_Models/ACU19EG.stp
80.0 x 80.0 x 12.4 mm
BOARD_OUTLINE
MT40A1G16RC-062E x 5
FFVC1760
VSON-10 x 2
AXK5A2137YG x 8
CSD87381P x 3
C1206
SOT23-5
TPS51200DRCR
MT40A256M16GE-075E x 4
SX2-3215
LED_0805
L4_2X4_2 x 3
LL0603 x 3
D7343 x 9
CC1206 x 38
L5_2X5_2 x 7
RR0603
R0603
RR0402 x 214
HCI100808R29Q-R18L x 2
CC0402 x 363
CC0603 x 43
CC0805 x 65
OSC3_2X2_5
SOT-23-5 x 2
OSC6-3225
SC70-6L
DSBGA8
MLP8 x 2
FC2QFN21 x 2
MAXIM_FC2QFN_35L
VQFN64
MARK x 8
MH_250H125 x 4
VFBGA_13X11_5

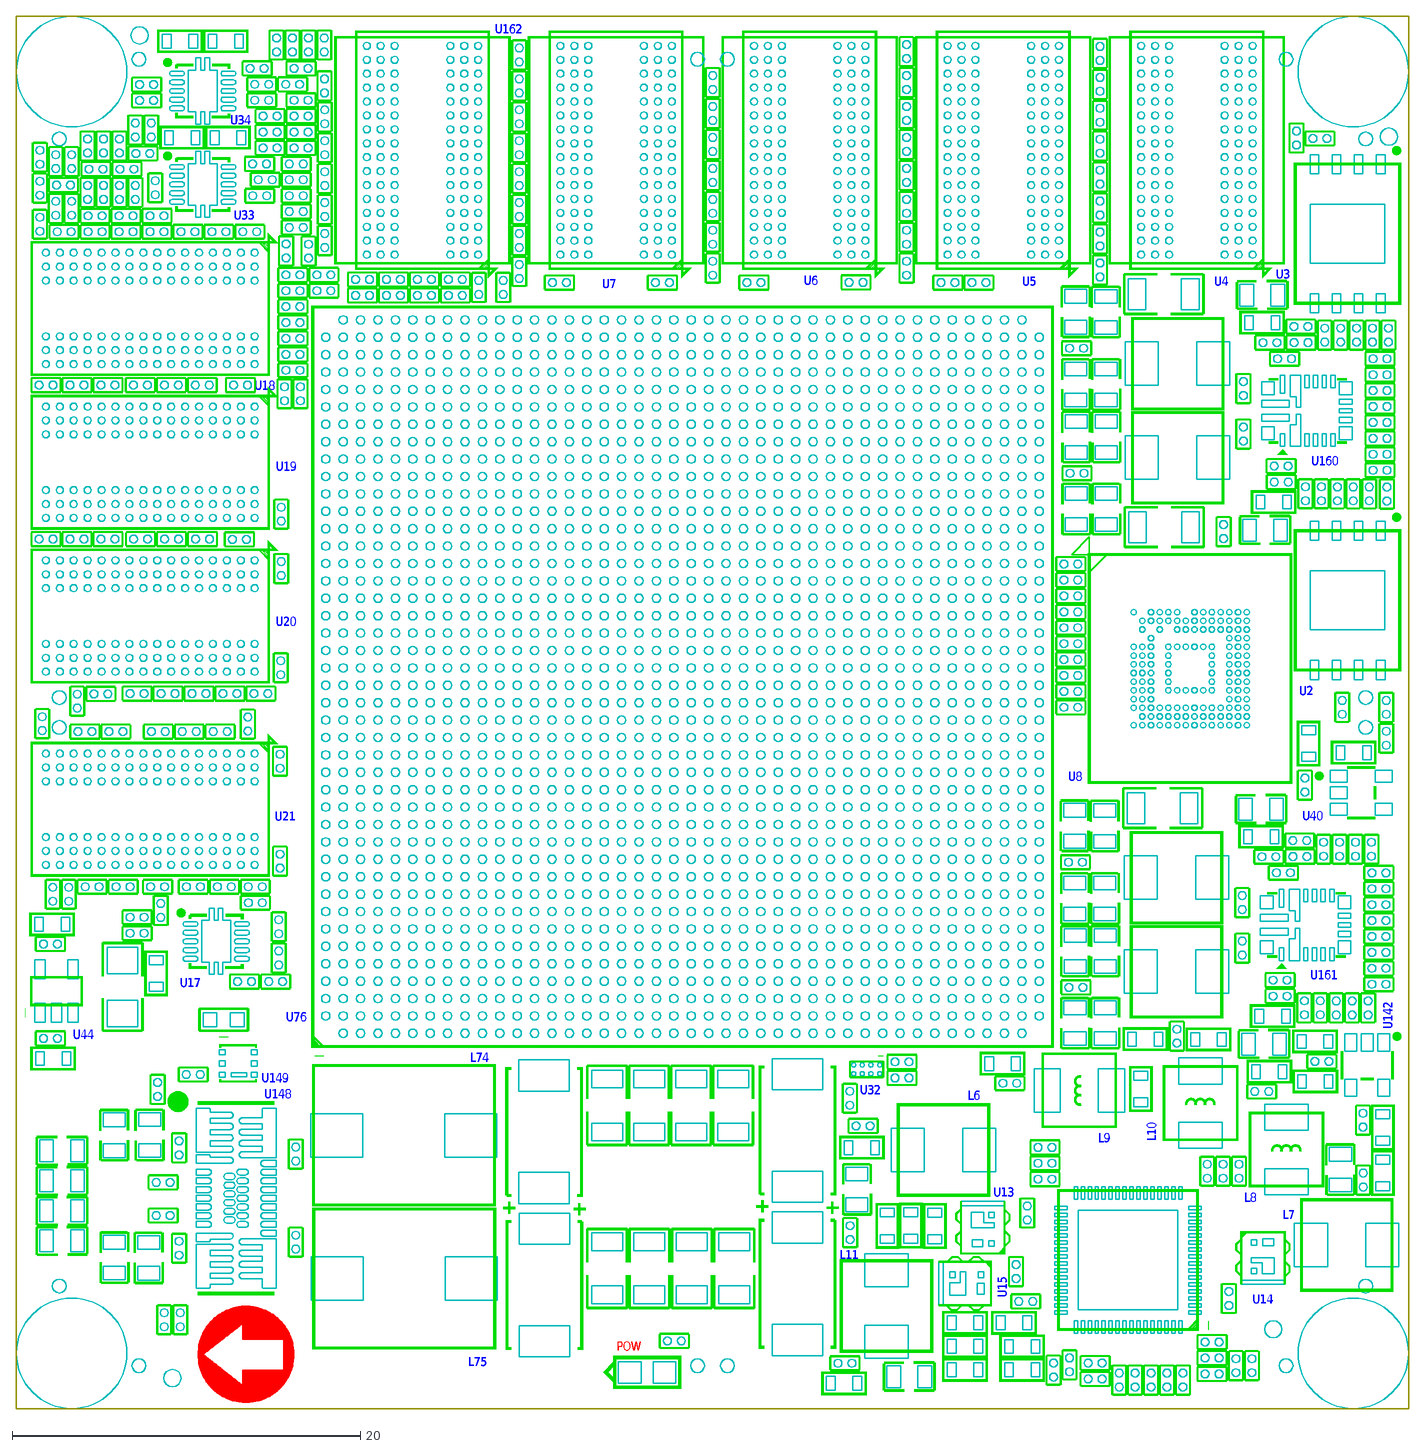
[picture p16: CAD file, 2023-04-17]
hardware/STEP_Models/ACU19EG_size_structure.dxf
U4
U5
U7
U6
U162
U76
U34
U33
U15
U13
U14
U44
U17
U18
U19
U20
U21
L9
L8
L10
L7
L6
L11
L75
L74
U142
U40
U149
U32
U2
U3
U160
U161
U148
U8
POW

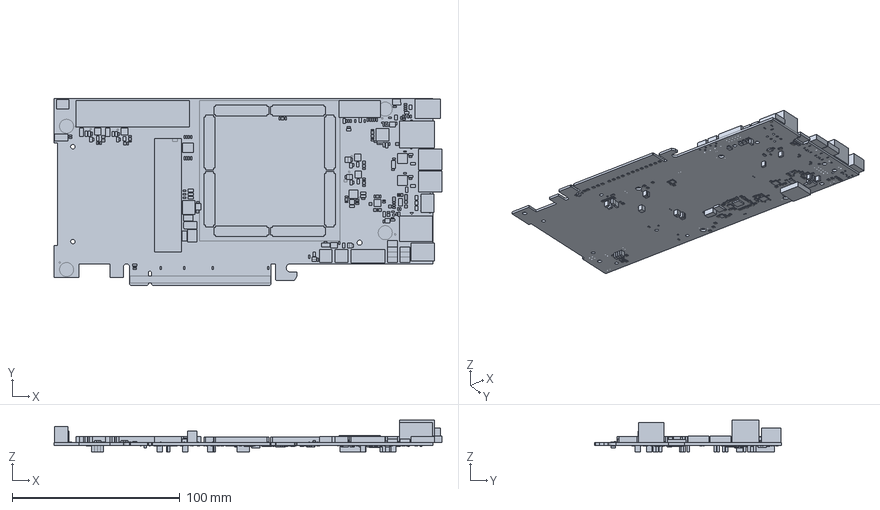
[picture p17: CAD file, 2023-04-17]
hardware/STEP_Models/Z19-P.stp
231.2 x 111.1 x 18.8 mm
BOARD
FAN
FID_C40M80
MARK1_5
PCIE_16LANE_EDGE
MH_250H125 x 4
R0603 x 4
SMA_P x 2
TS-026-3_3D8
ASP_134486_MAIN_FEMALE_S_1
LED_D3_WX2
H2X1 x 2
ASP_134486_MAIN_FEMALE_S
R0805 x 6
MICRO8
L0603 x 2
OSC6-3225 x 2
8S1_SOIC8
SX2-1205
QFN40
USB3320C
C1206
AXK6A2337YG x 8
CON2_1_27P
XH2-2_54_WHITE x 2
D7343
R1210
FCTSOT23-6
QFN24_RTW
SOT-223
L5_4X5_2
L4_4X4_2 x 4
PVQFN-N16
MICRO_SD
MDT420M02001_PCIE
JTAG-10
QFN24-050-4X4-H2R7
C0805 x 39
SON10_3X3
TSSOP_14
4P4_1_27MM
BAS16XV2T1G x 2
WLCSP12
SOT23-3 x 6
QFN_7X7
SOT-23 x 3
DO-214AC x 7
FUSE_1812
CON_MOL_5569_6P
WQFN30
TSSOP8 x 2
LL0603 x 11
GE_RJ45
SOT23-5
LED_0805 x 5
QFN-28 x 2
SOD-123
C0402 x 211
R0402 x 159
SOT23-6 x 10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

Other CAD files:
hardware/STEP_Models/Z19-P_size_structure.dxf

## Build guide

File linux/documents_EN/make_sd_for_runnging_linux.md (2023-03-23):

[Back to Home](../)
## Start the linux on the development board from the SD card

---
### 1.Adjust the dial switch
Adjust the dial switch on the development board to the state of starting from the SD card, as shown below:\
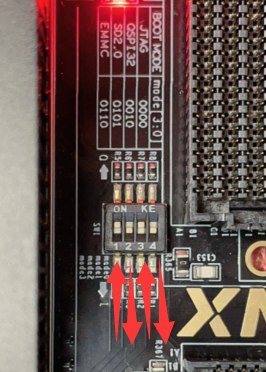
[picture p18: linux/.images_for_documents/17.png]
\
This position of the dial -dial switch is in the development board:\
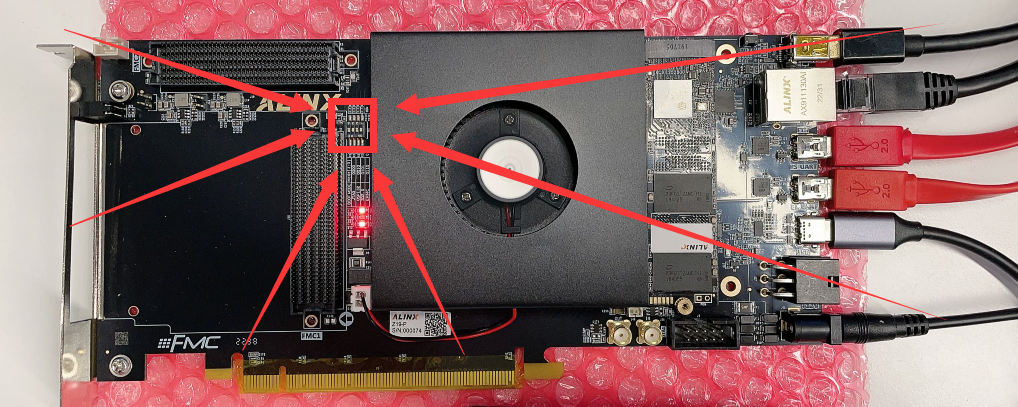
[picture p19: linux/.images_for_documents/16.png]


---
### 2.Set SD card partition
Next, you need to make the SD card for launching Linux. Connect the SD card (such as a card reader) to the Ubuntu system, and then open the DISKS tool in the Ubuntu system:\
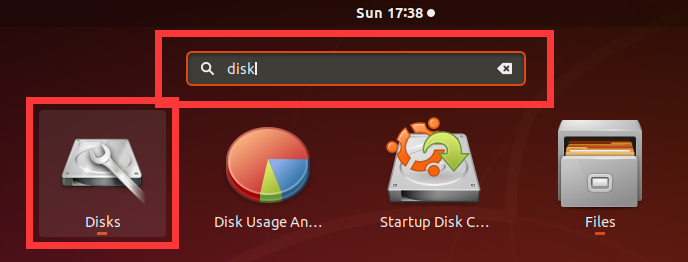
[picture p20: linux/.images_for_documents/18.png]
\
My SD card is the **31 GB Drive** here. Select it, you can see that there are three areas in the SD card:\
a. FAT type partition named **BOOT**\
b. Ext4 type partition named **ROOTFS**\
c. Free Space\
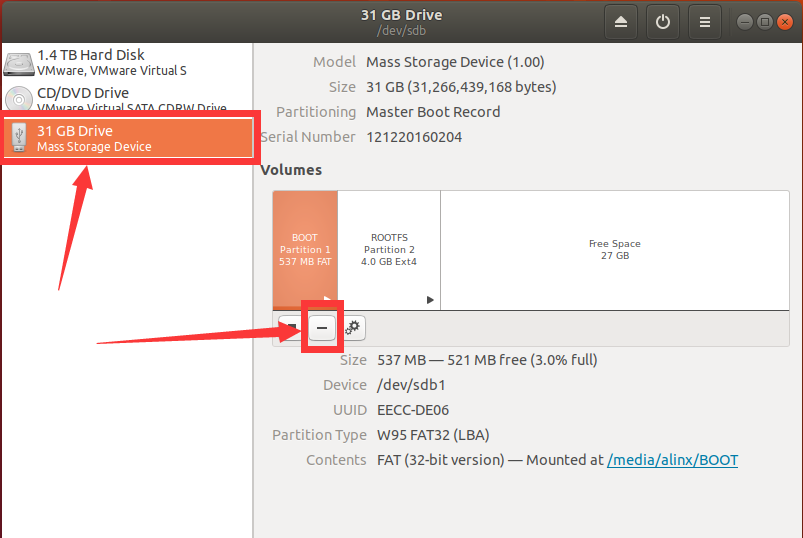
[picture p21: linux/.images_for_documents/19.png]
\
This is the state we need. If your SD card is in the same state (there is no strict requirement on the size of the partition), just skip step [2]. However, in order to demonstrate a complete process, I will restore the SD to the state without partition, select the corresponding partition, click the \" **-** \" icon to delete the current partition, and finally change to the state as shown below:\
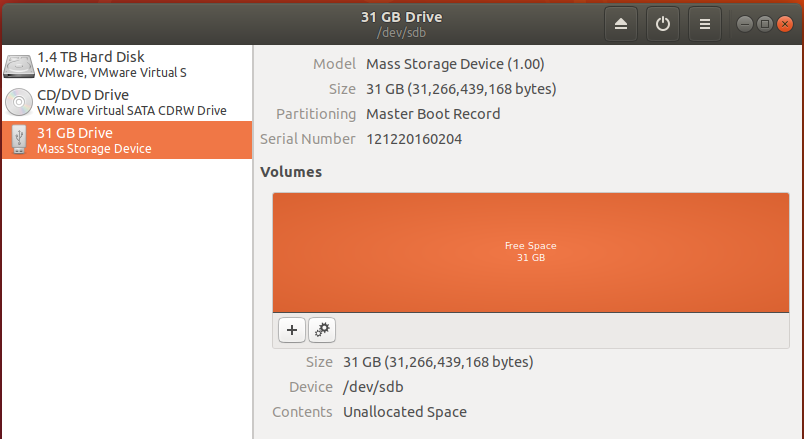
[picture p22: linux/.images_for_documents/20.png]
\
Click the \" **+** \" icon to create a new partition. The first partition needs to be in the format of **FAT**, with a size of 2G and a name of **BOOT**:\
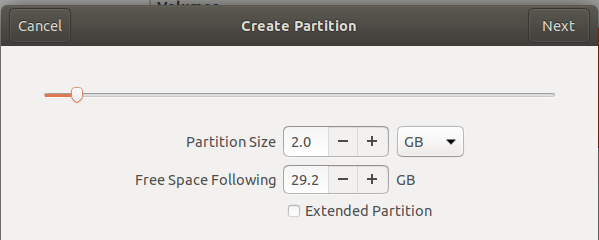
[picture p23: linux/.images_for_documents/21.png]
\
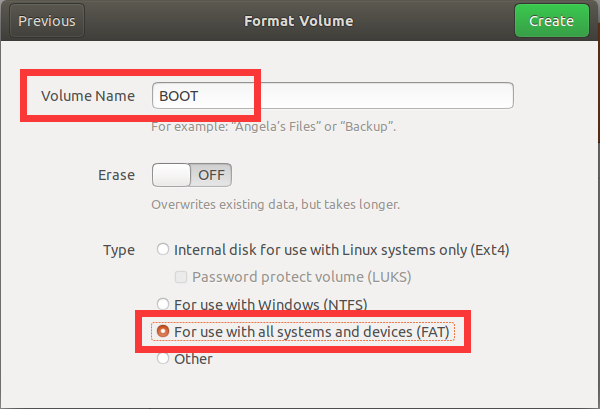
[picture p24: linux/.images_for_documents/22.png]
\
Click the **Create** button to complete the partition creation, and click \" **▶** \" button mount partition:\
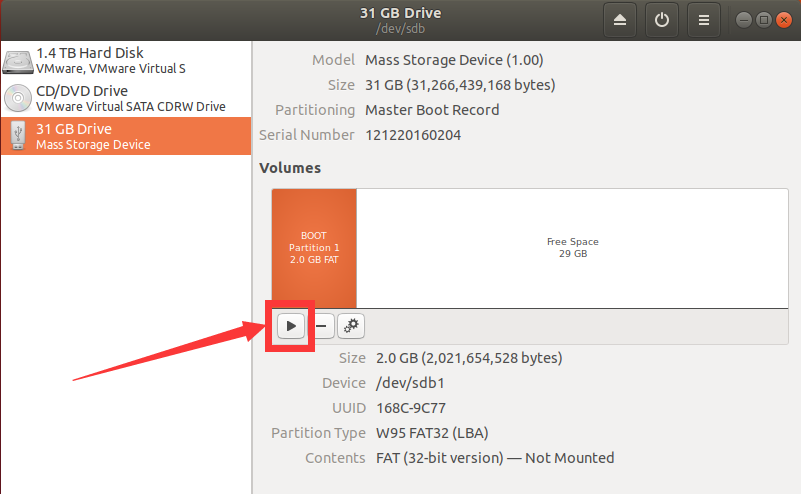
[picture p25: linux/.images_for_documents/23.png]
\
Click **Free Space** to create a second partition using similar steps. Select **Ext4** as the format. The size allocation is 20G (adjusted according to your actual needs and restrictions). The name is **ROOTFS**:\
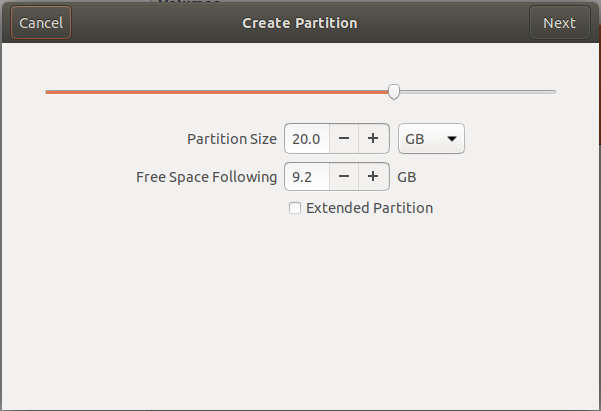
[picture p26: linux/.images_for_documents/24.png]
\
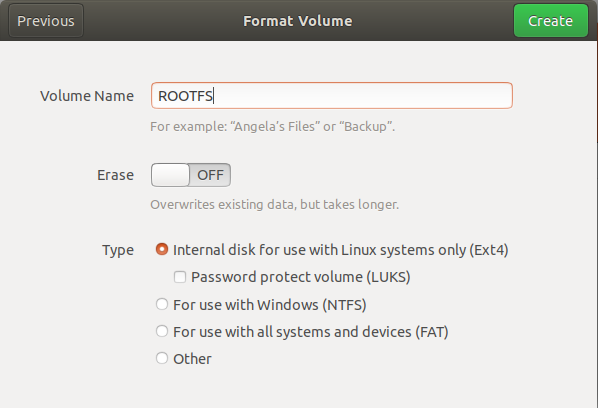
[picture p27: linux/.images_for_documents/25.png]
\
The final status is shown in the following figure. Note that you need to mount both partitions:\
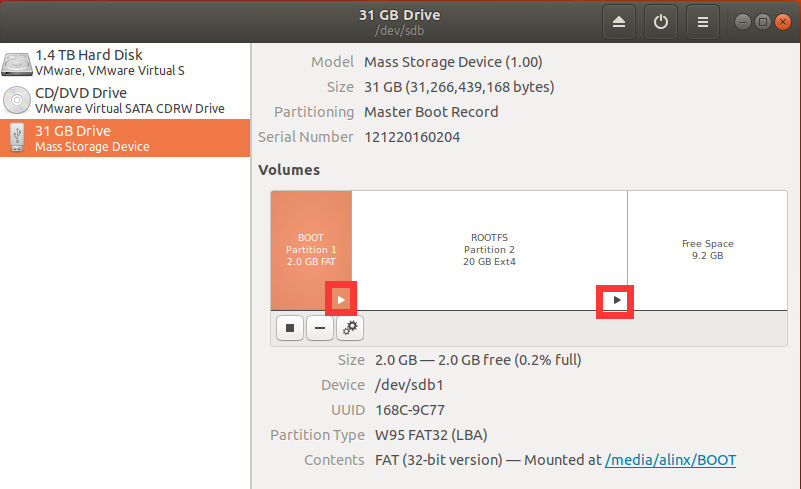
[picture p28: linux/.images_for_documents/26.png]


---
### 3.Populate SD card partitions
After the partition of the SD card is completed, copy the files needed to start the system to the corresponding partition.\
Ps: You can find *boot. scr*, *BOOT. bin*, *image. ub*, *rootfs. tar. gz*  in the release version. You can also compile the petalinux project to obtain these files.\
Copy the *boot.scr*, *BOOT.bin*, and *image.ub* files to the **BOOT** partition:\
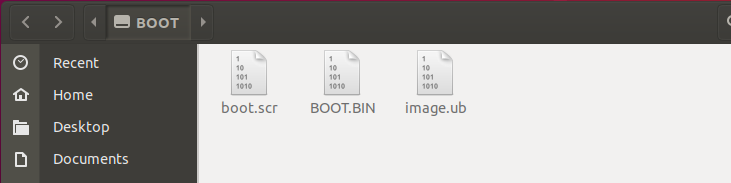
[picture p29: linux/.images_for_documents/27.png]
\
Extract *rootfs.tar.gz* to the **ROOTFS** partition with root privileges, open the terminal in the path of *rootfs.tar.gz*, and enter the following command:\
`sudo tar zxvf ./rootfs.tar.gz -C /media/alinx/ROOTFS/ && sync`\
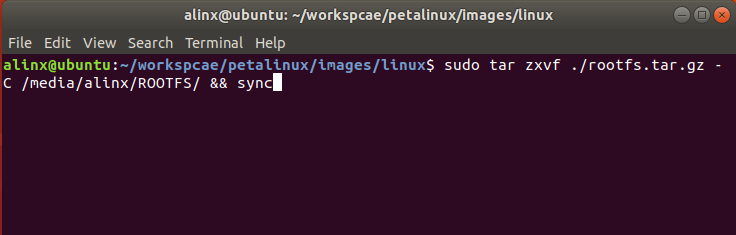
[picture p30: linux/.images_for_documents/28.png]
\
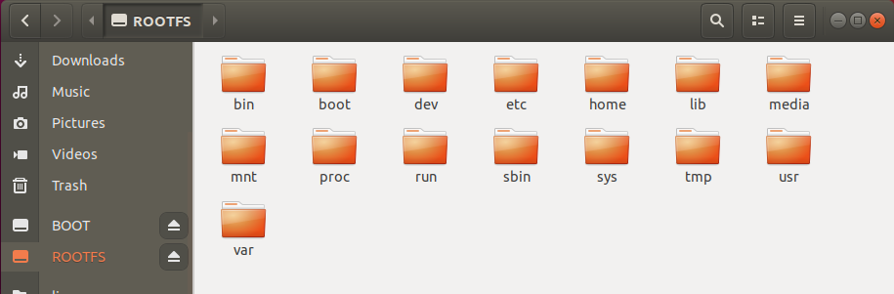
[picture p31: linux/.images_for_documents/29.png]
\
Then eject the SD card from Ubuntu.

---
### 4.Start Linux
Insert the SD card just made into the SD card slot of the development board:\
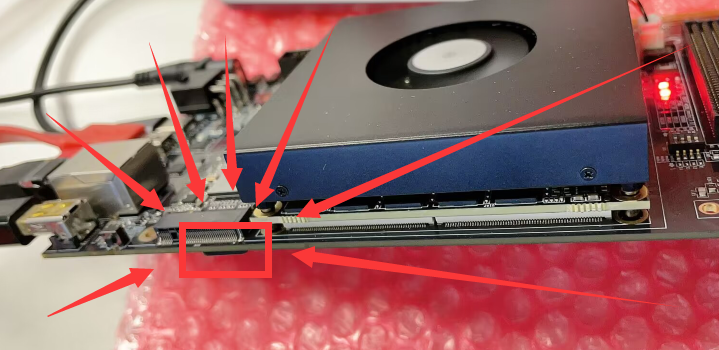
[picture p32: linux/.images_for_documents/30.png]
\
Connect PS_UART to PC (***The driver of CP210x needs to be installed on the PC*** ):\
\
Open the serial port tool, select the COM port we just connected, set the baud rate to 115200, close the flow control, and click the OK button:\
\
Connect 12V power supply:\
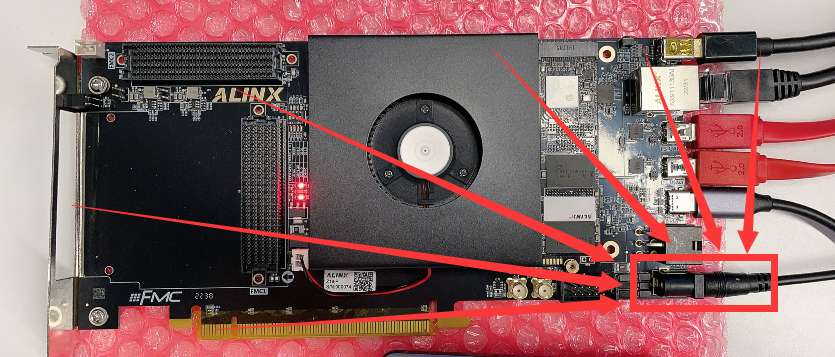
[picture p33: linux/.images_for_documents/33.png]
\
You can see the output information in the serial port tool:\
\
The system has been started successfully. Enter the user name **root** and password **root** to log in to the system.

---
---
- Visit [ALINX official website](https://www.alinx.com) for more information.

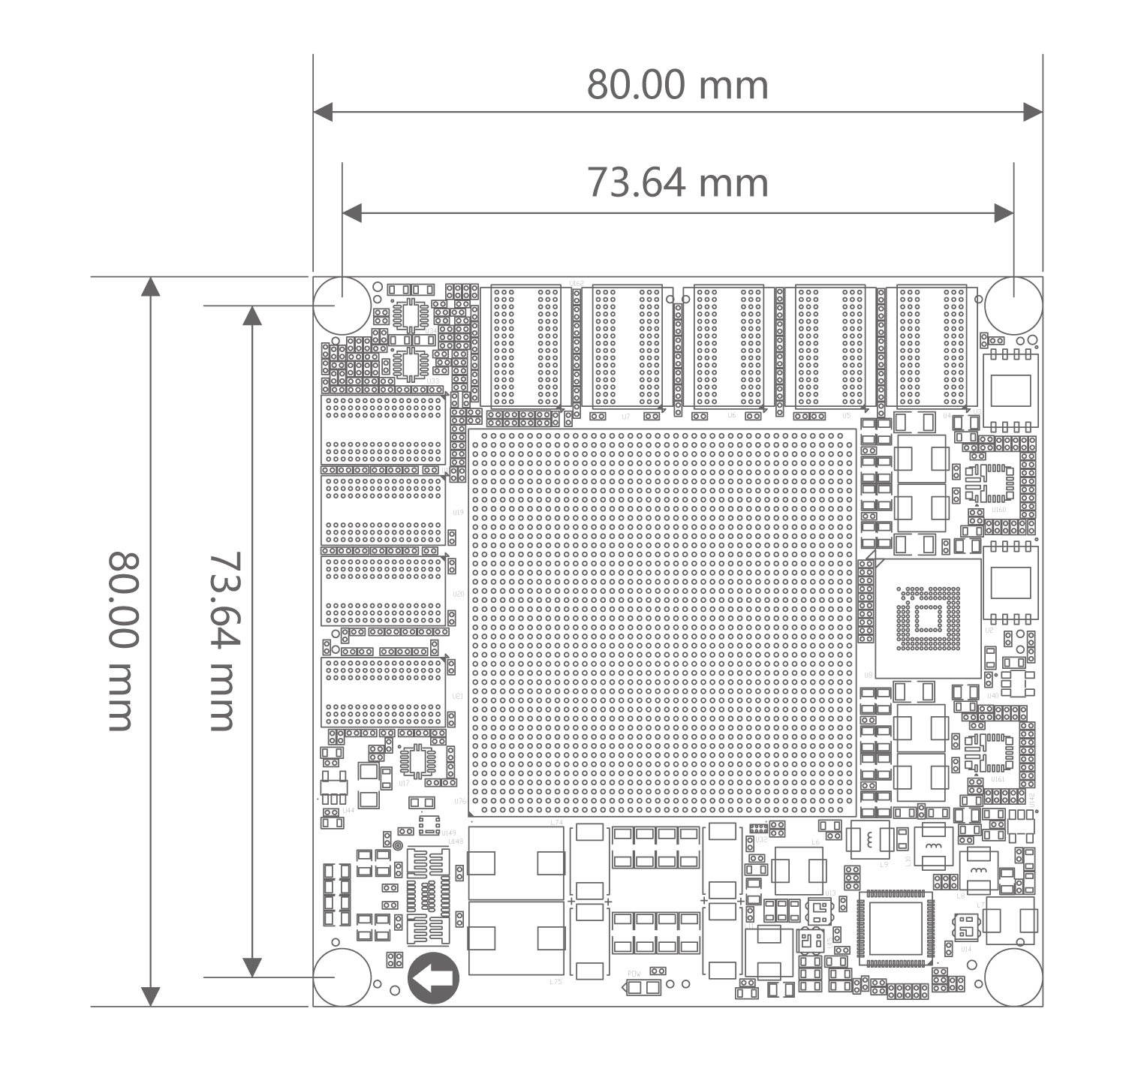
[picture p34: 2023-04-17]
hardware/STEP_Models/ACU19EG_size_structure.png

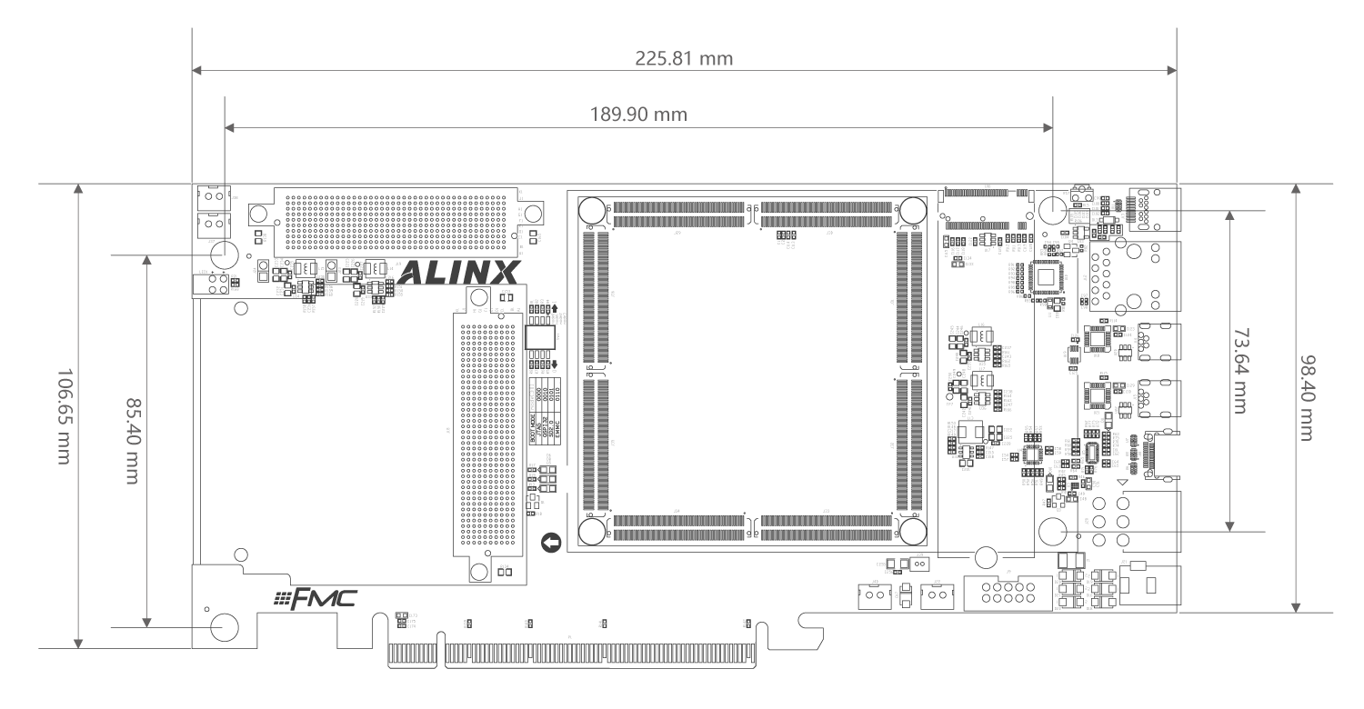
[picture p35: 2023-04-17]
hardware/STEP_Models/Z19-P_size_structure.png

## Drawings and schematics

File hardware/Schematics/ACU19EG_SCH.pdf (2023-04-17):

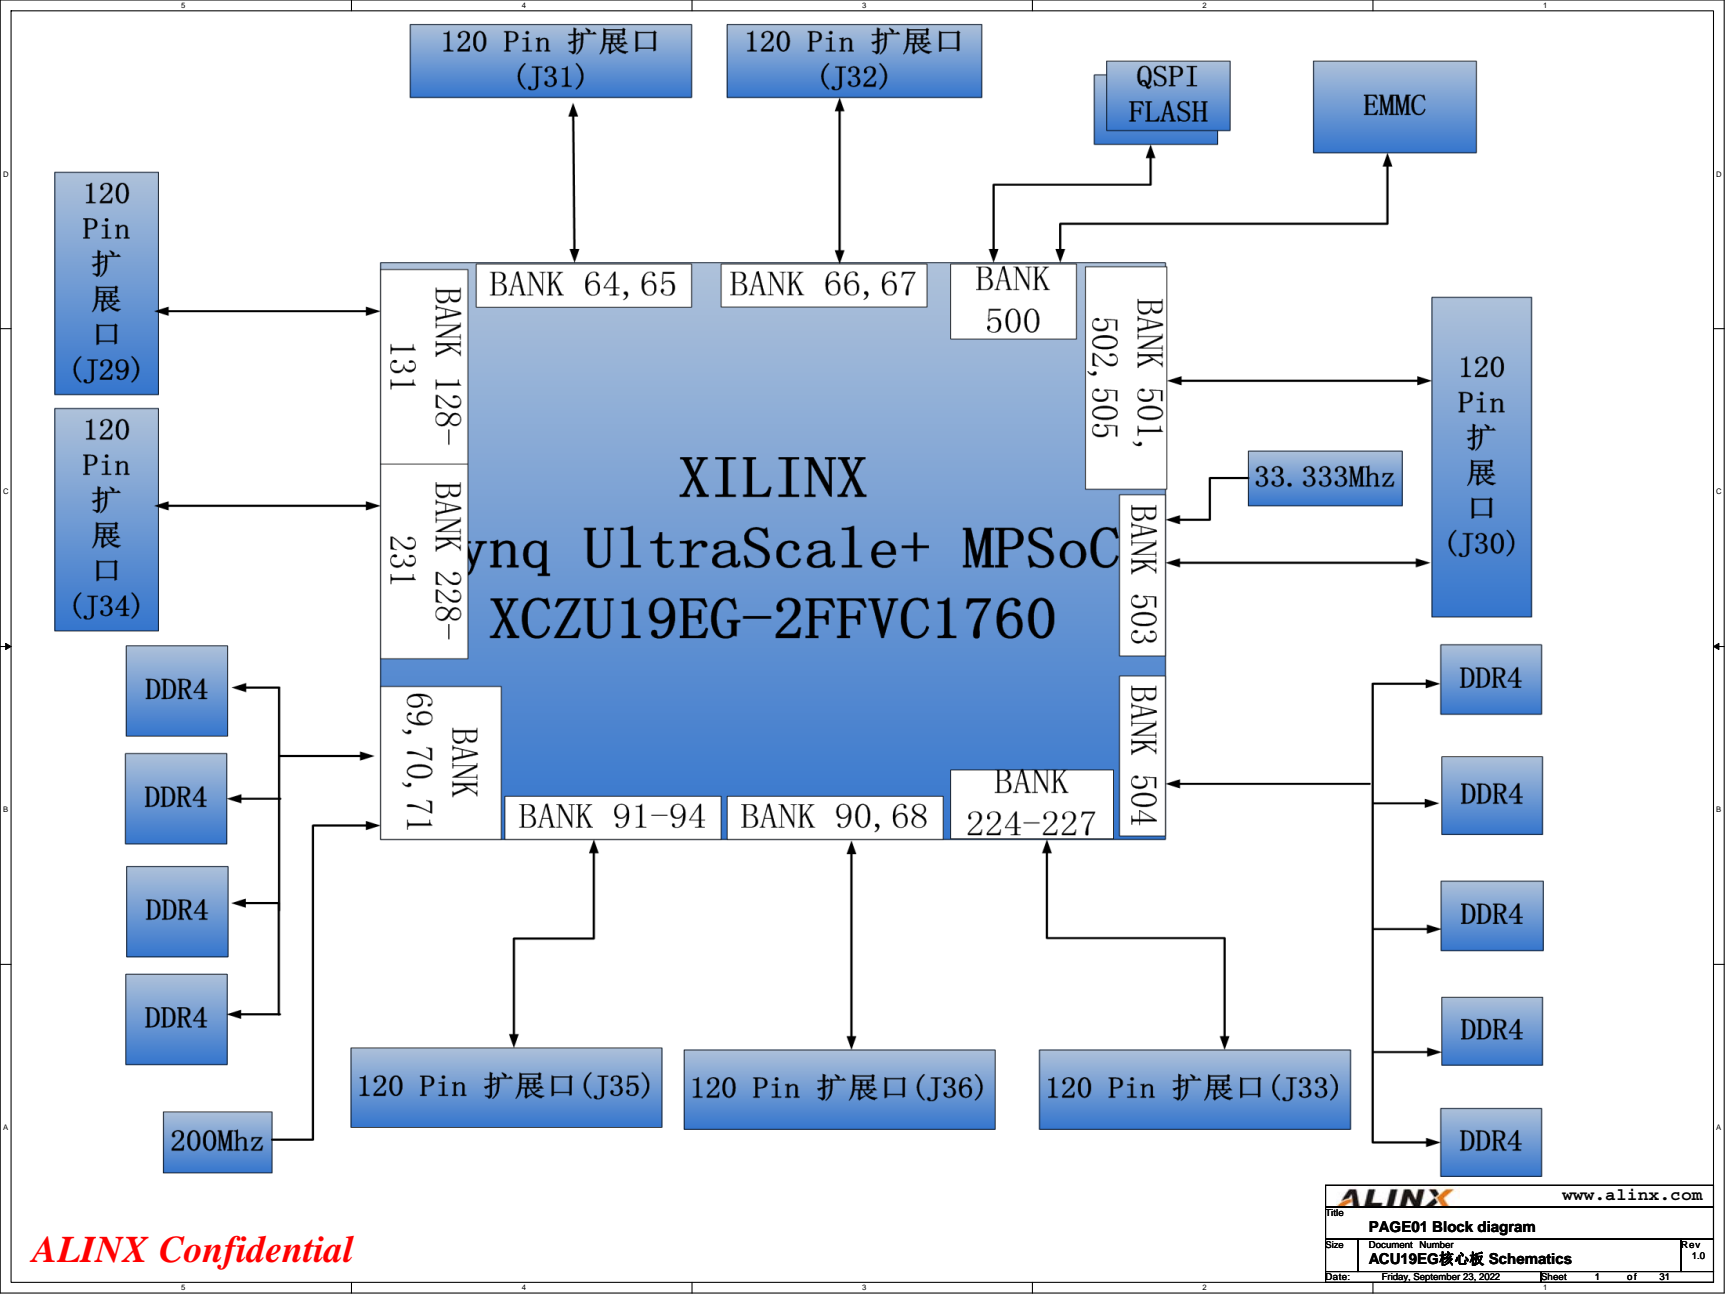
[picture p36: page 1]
ALINX Confidential; Title; PAGE01 Block diagram

www.alinx.com

Size | Document Number ACU19EG核心板 Schematics | Rev 1.0

Date: Friday, September 23, 2022 Friday, September 23, 2022 Friday, September 23, 2022 | Sheet 1 1 1 of 31 31 31

# MODE[3:0]

0000 | PS JTAG | PS JTAG Interface

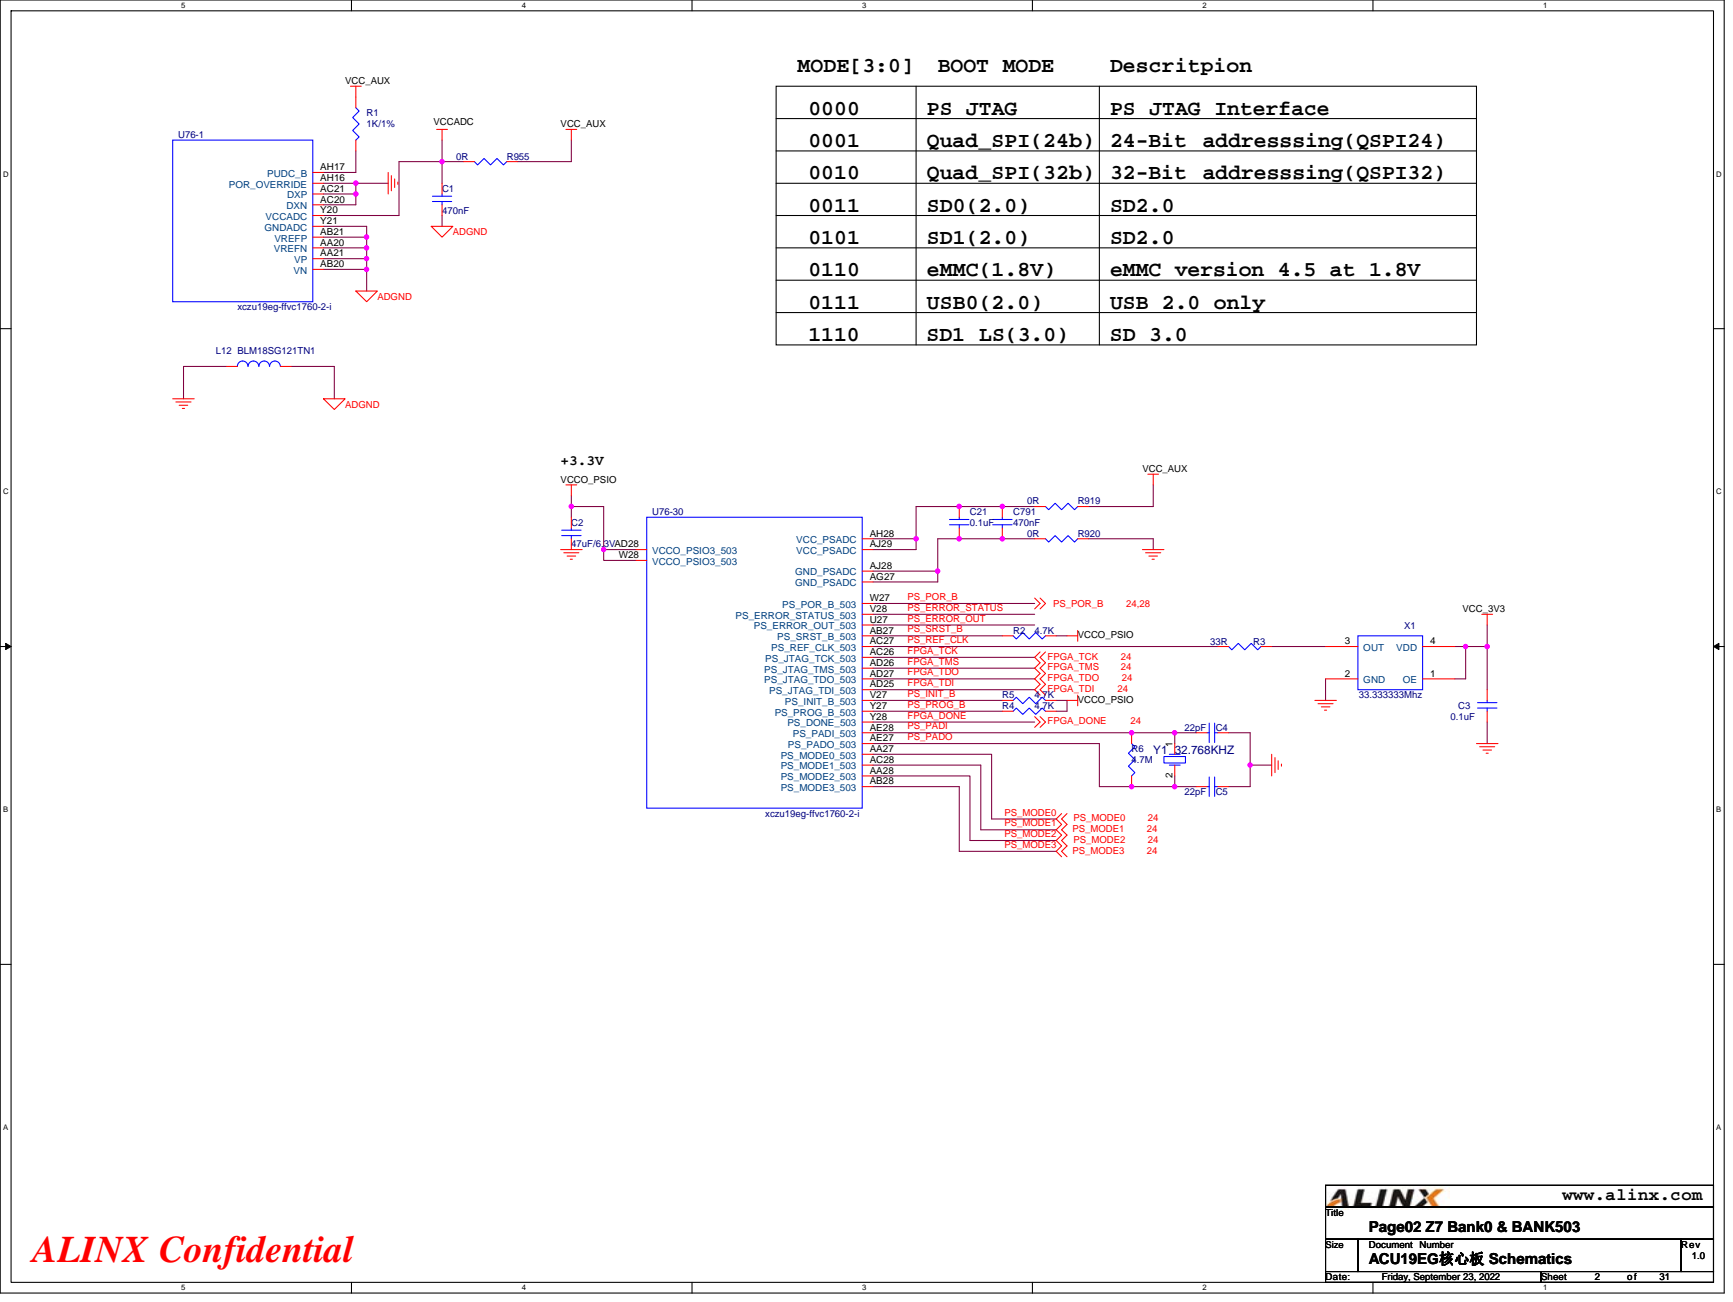
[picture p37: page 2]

0001 | Quad_SPI(24b) | 24-Bit addresssing(QSPI24)
0010 | Quad_SPI(32b) | 32-Bit addresssing(QSPI32)
0011 | SD0(2.0) | SD2.0
0101 | SD1(2.0) | SD2.0
0110 | eMMC(1.8V) | eMMC version 4.5 at 1.8V
0111 | USB0(2.0) | USB 2.0 only
1110 | SD1 LS(3.0) | SD 3.0

VCC_AUX

PS_PADO

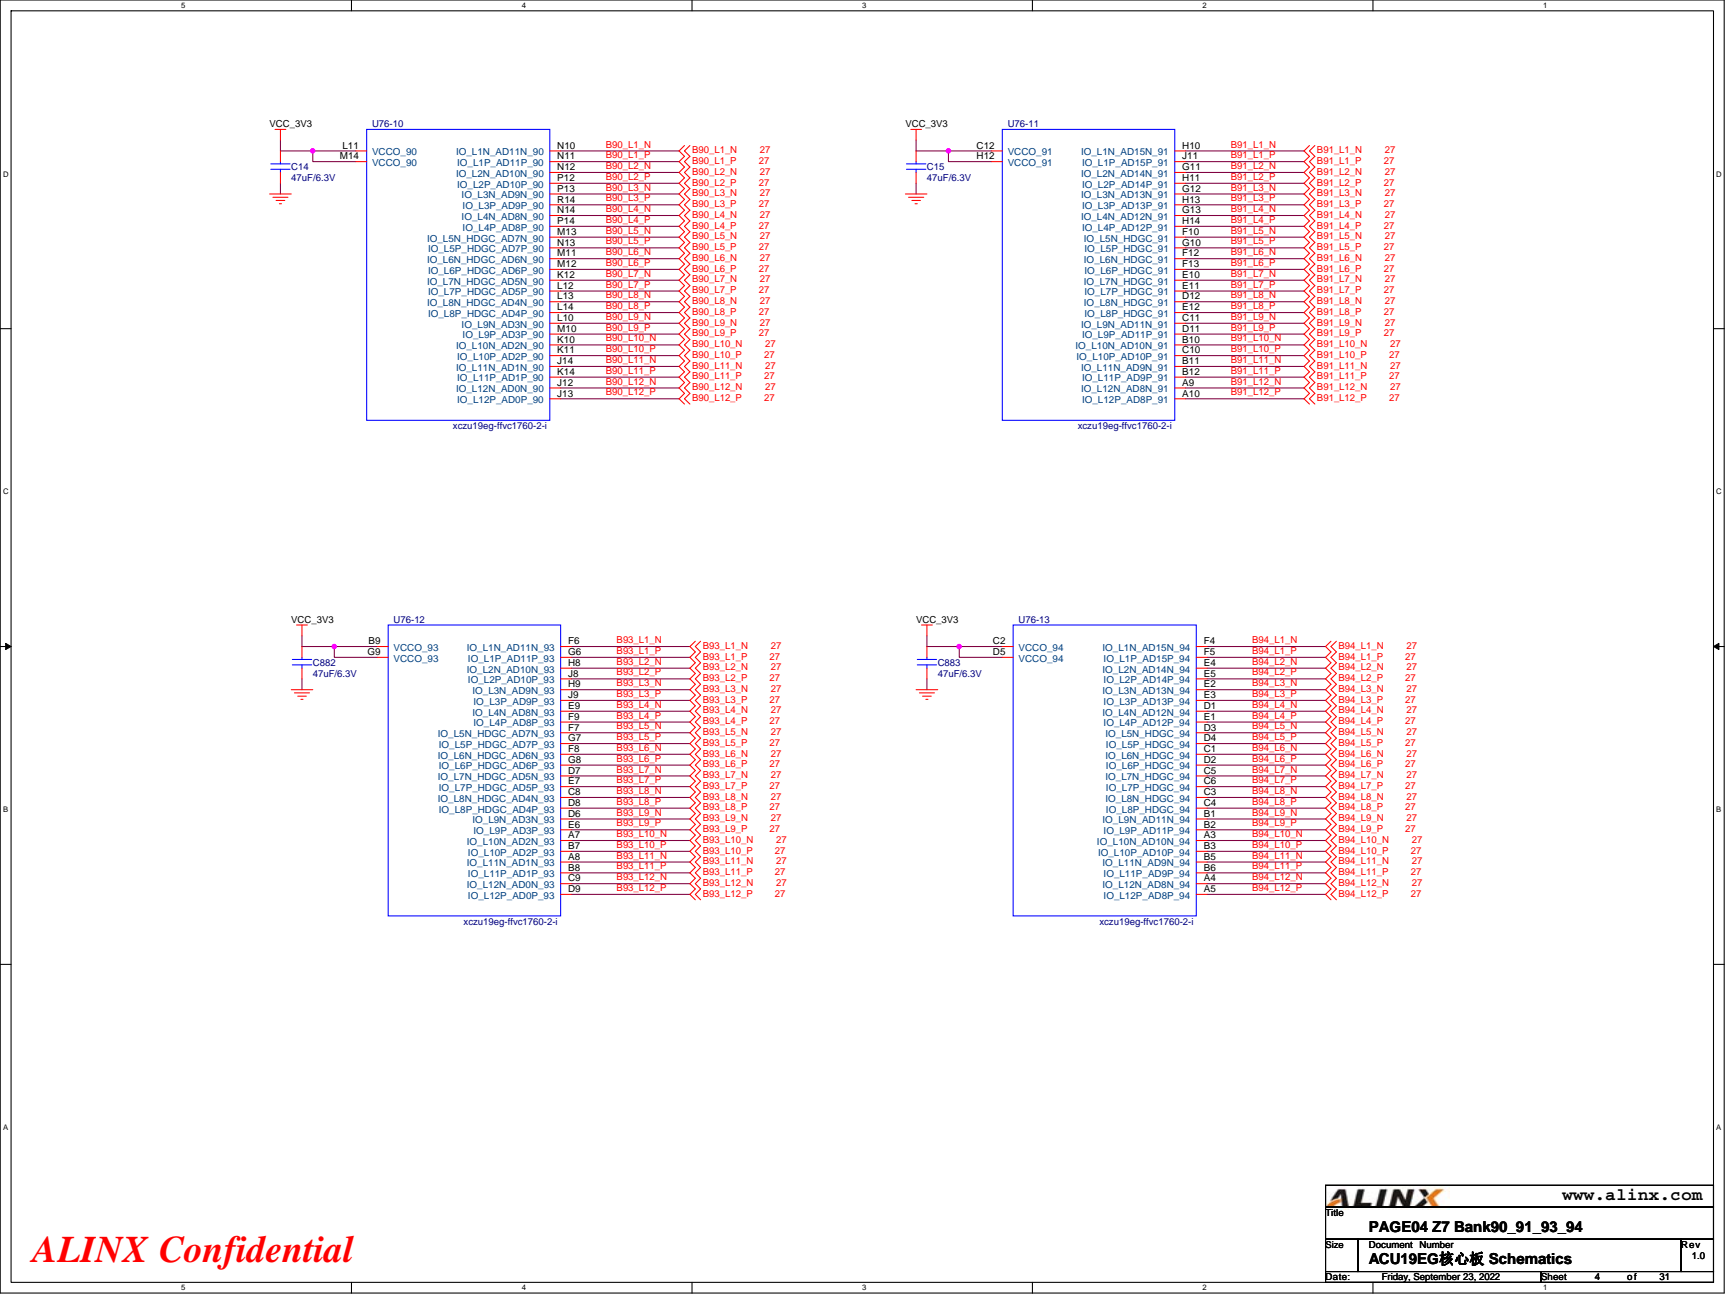
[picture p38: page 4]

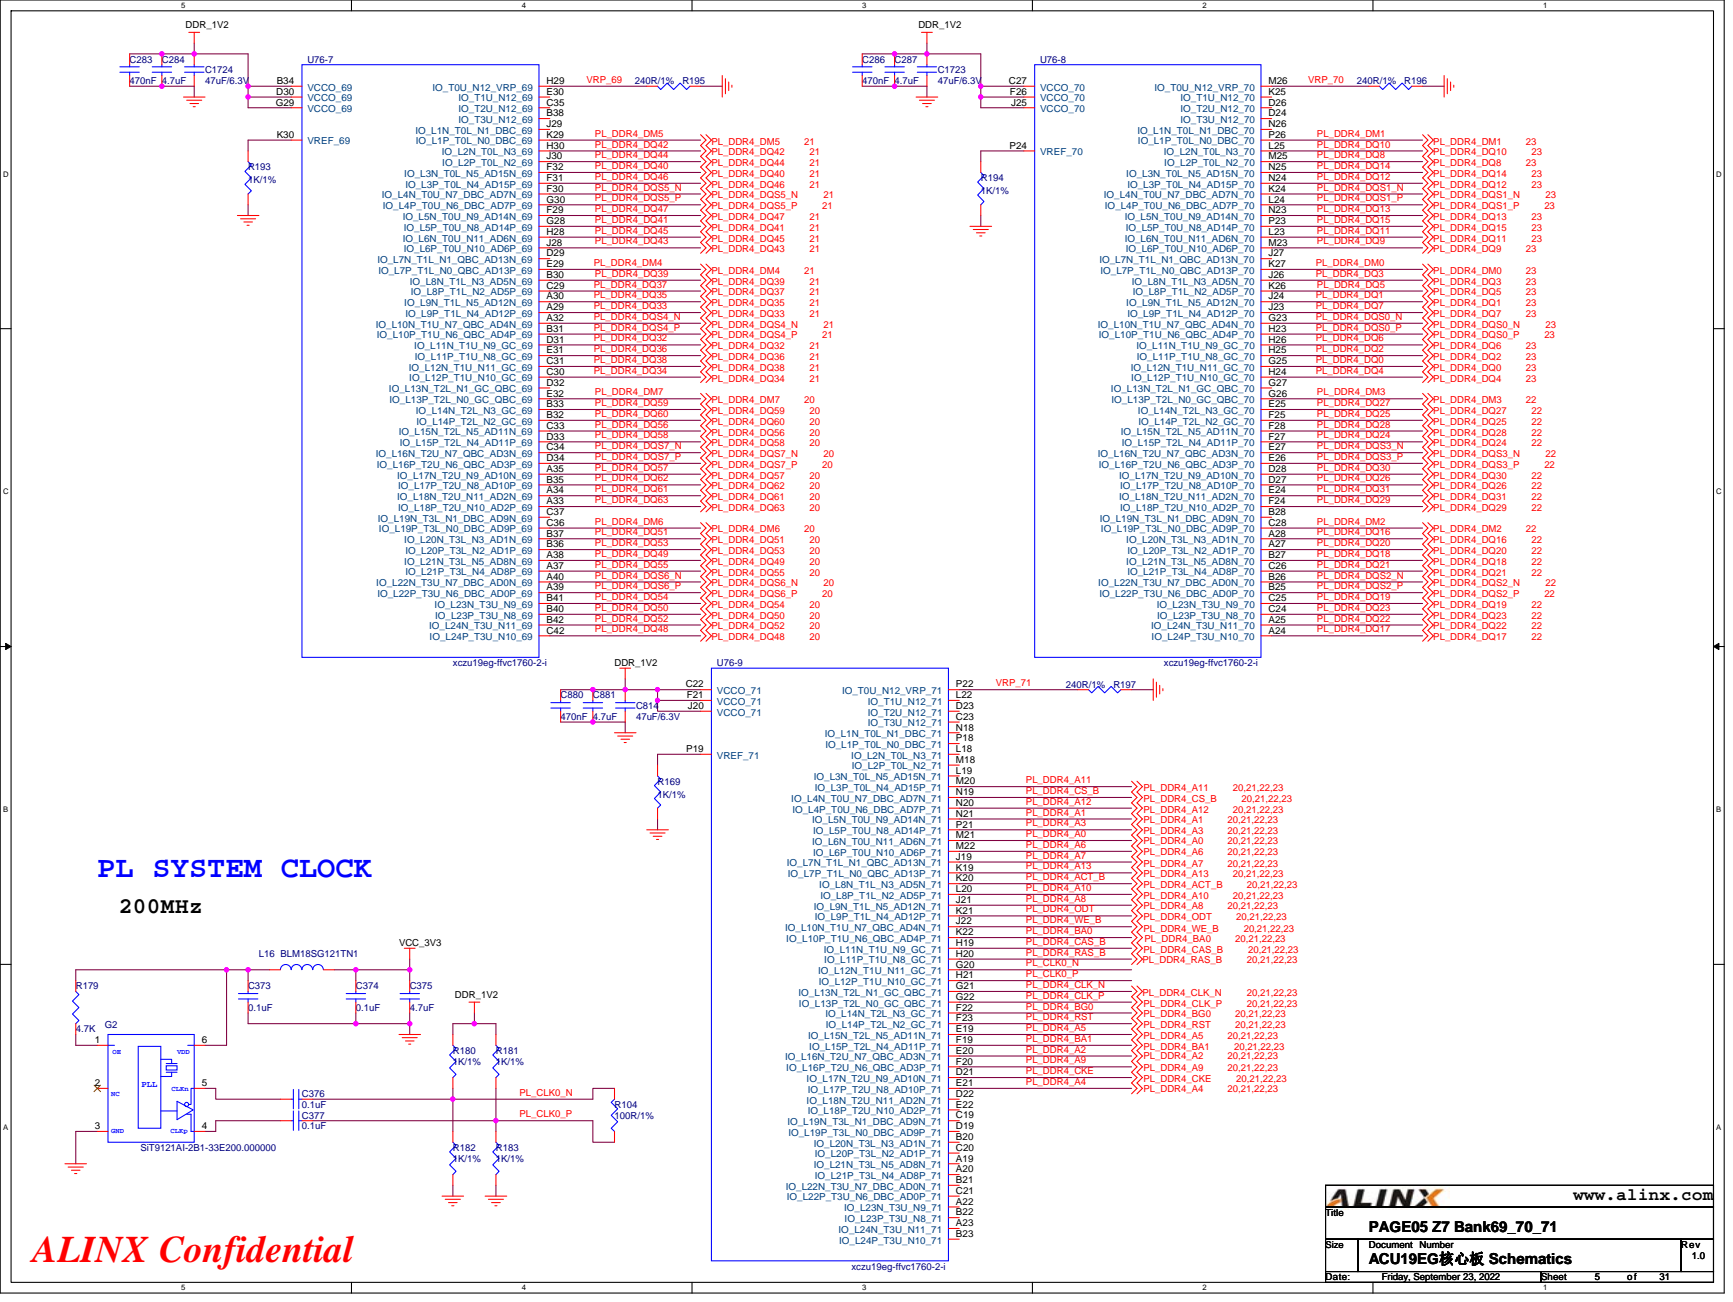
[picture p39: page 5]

+1.8V OR +1.2V | +1.8V OR +1.2V

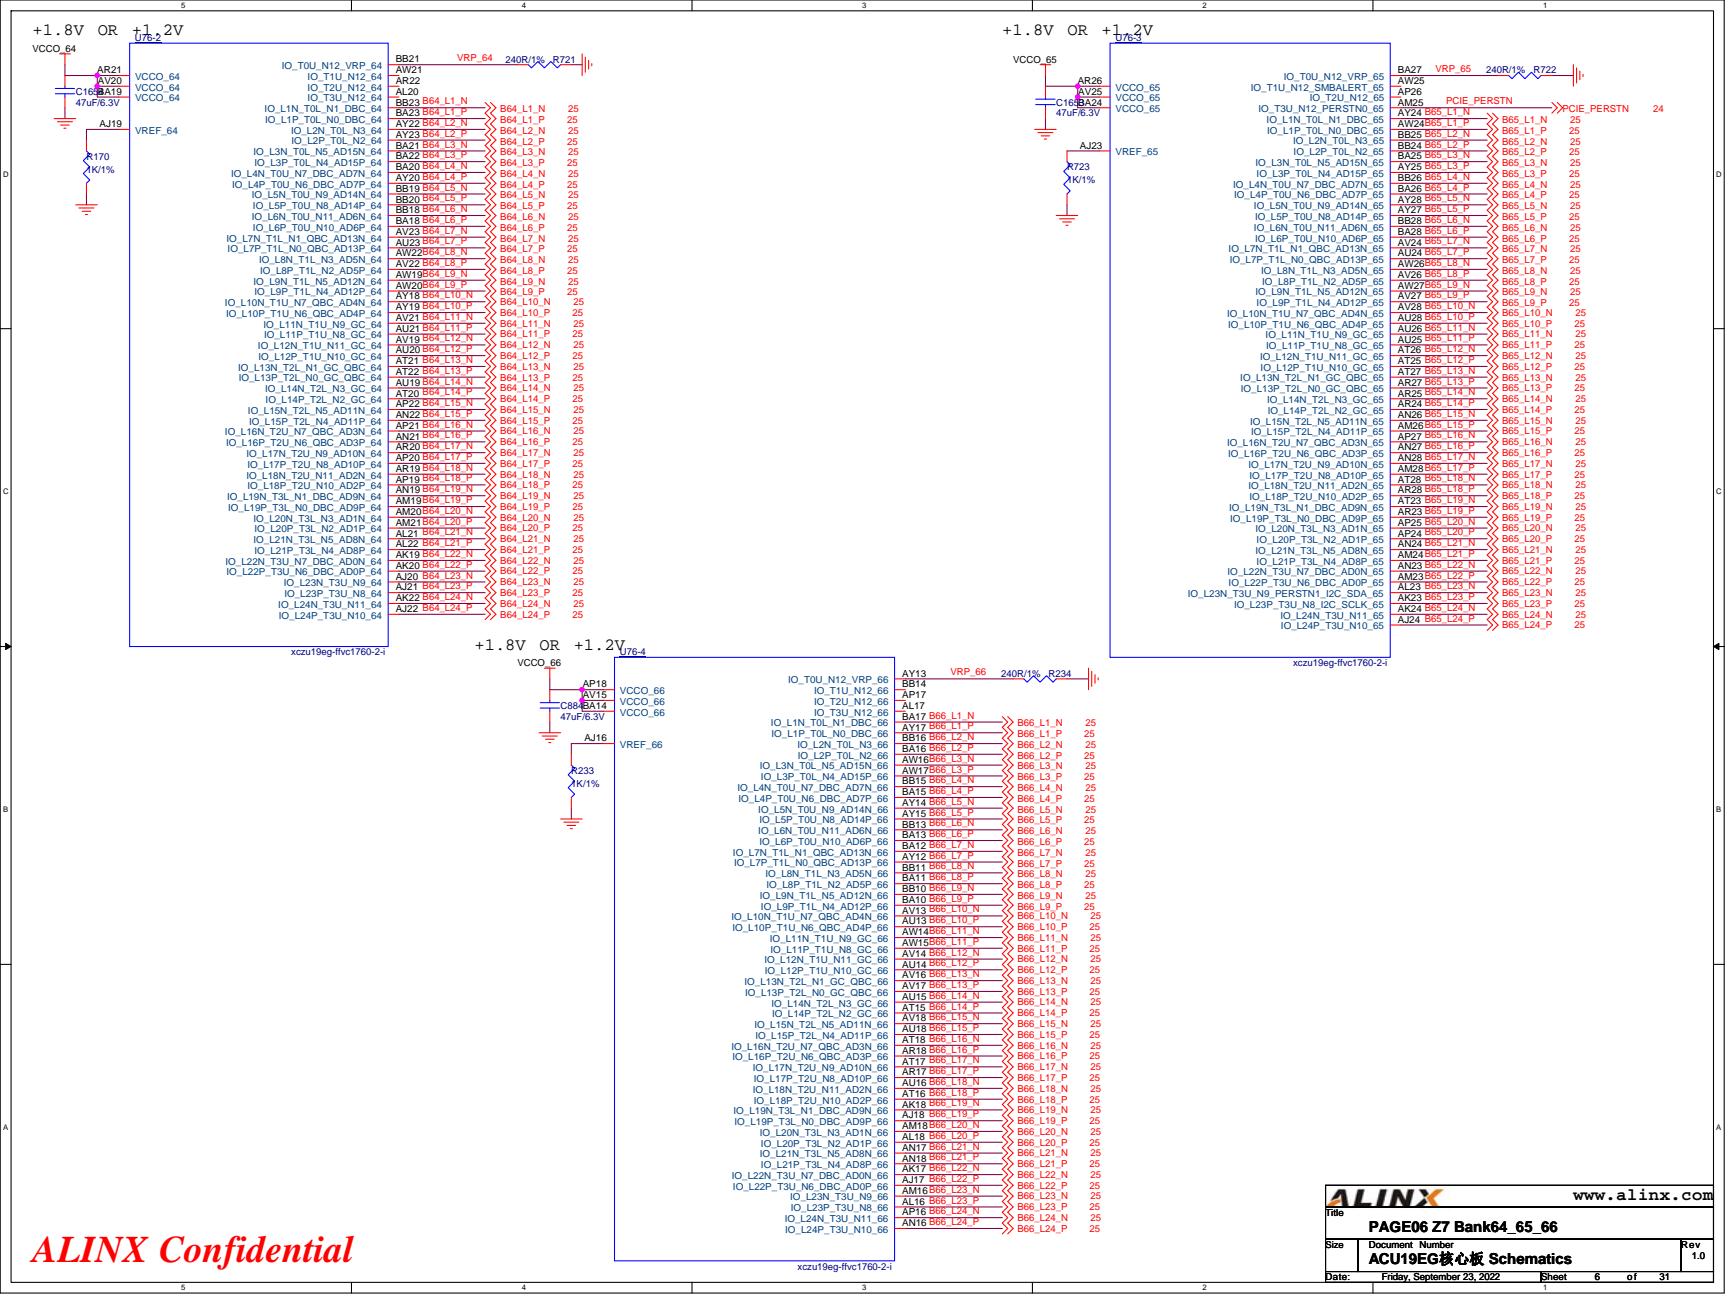
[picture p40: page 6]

+1.8V or +1.2V | +1.8V or +1.2V

1.8V

0.85V

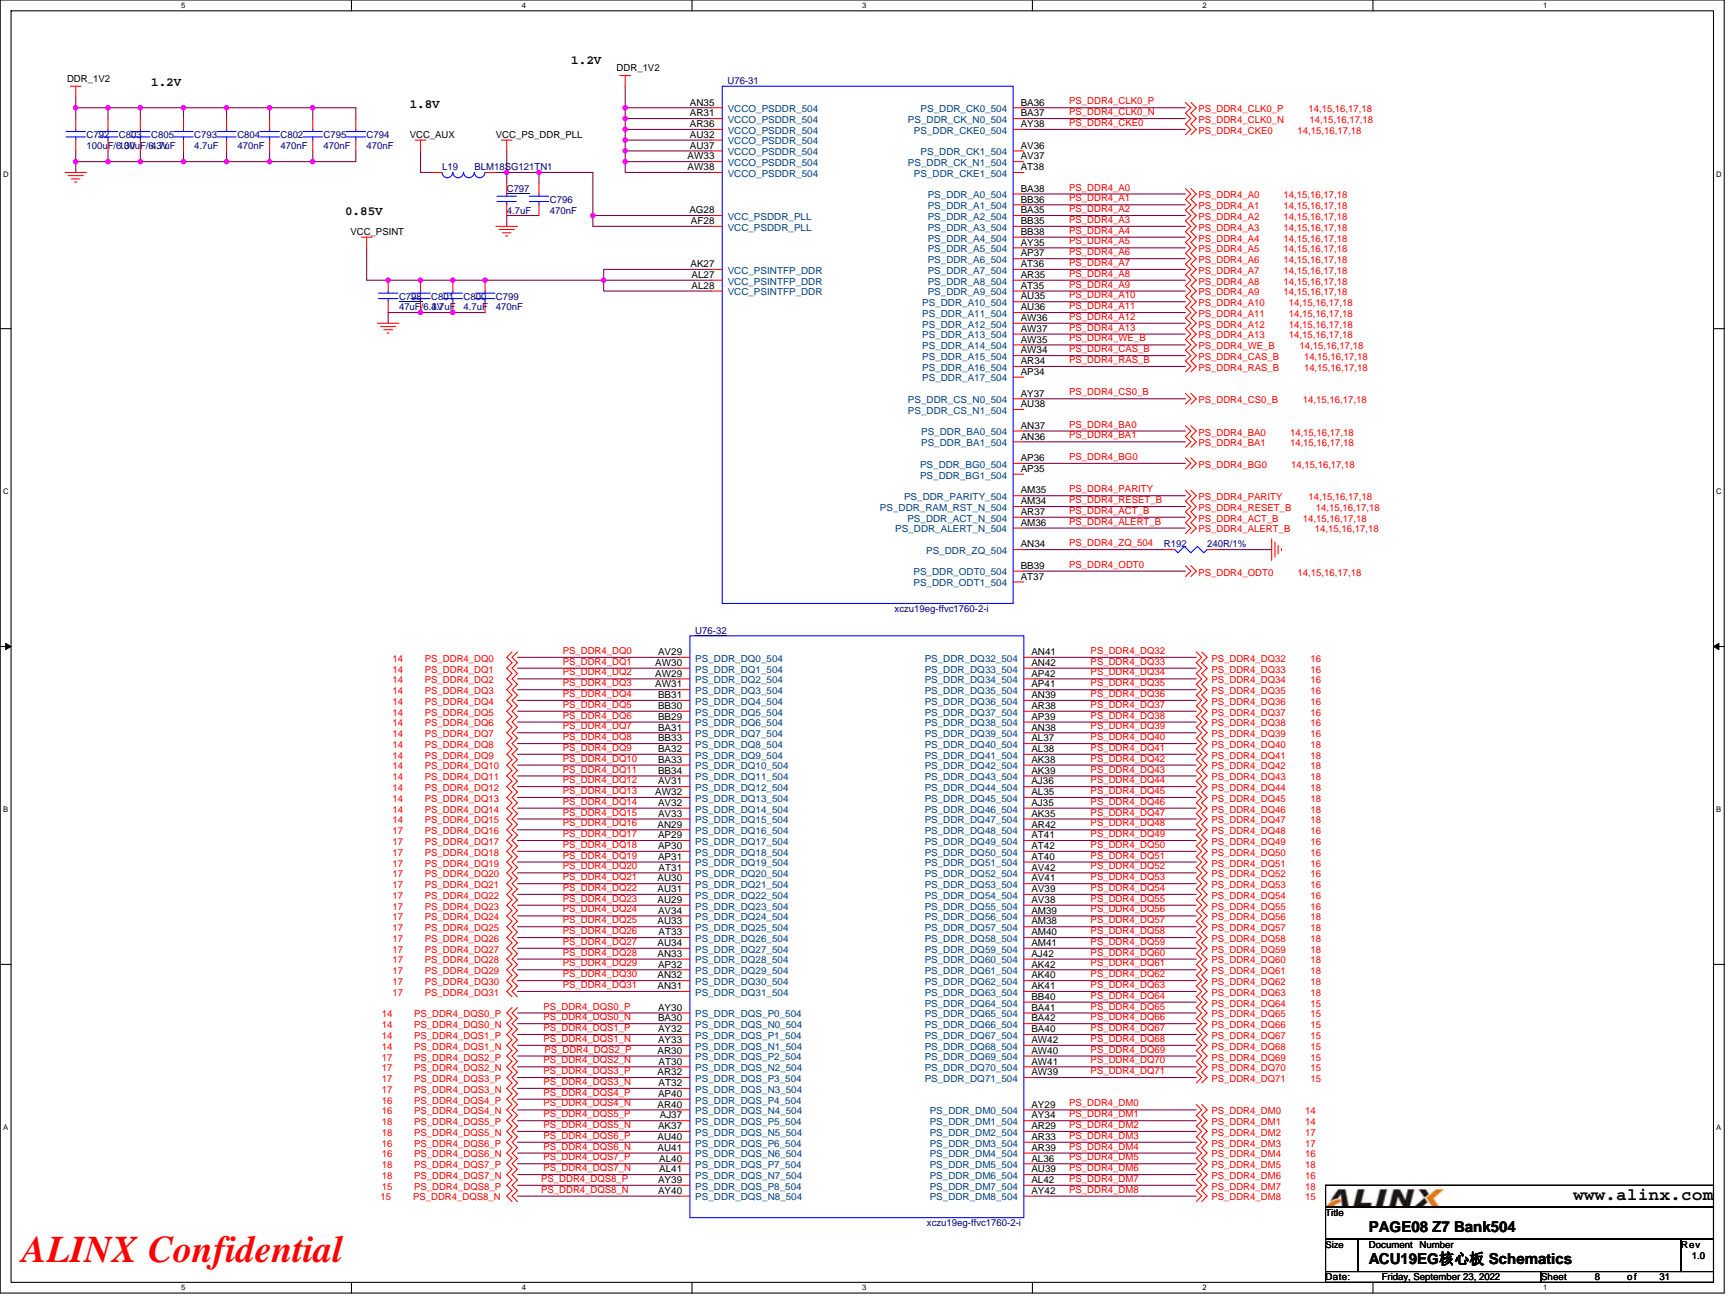
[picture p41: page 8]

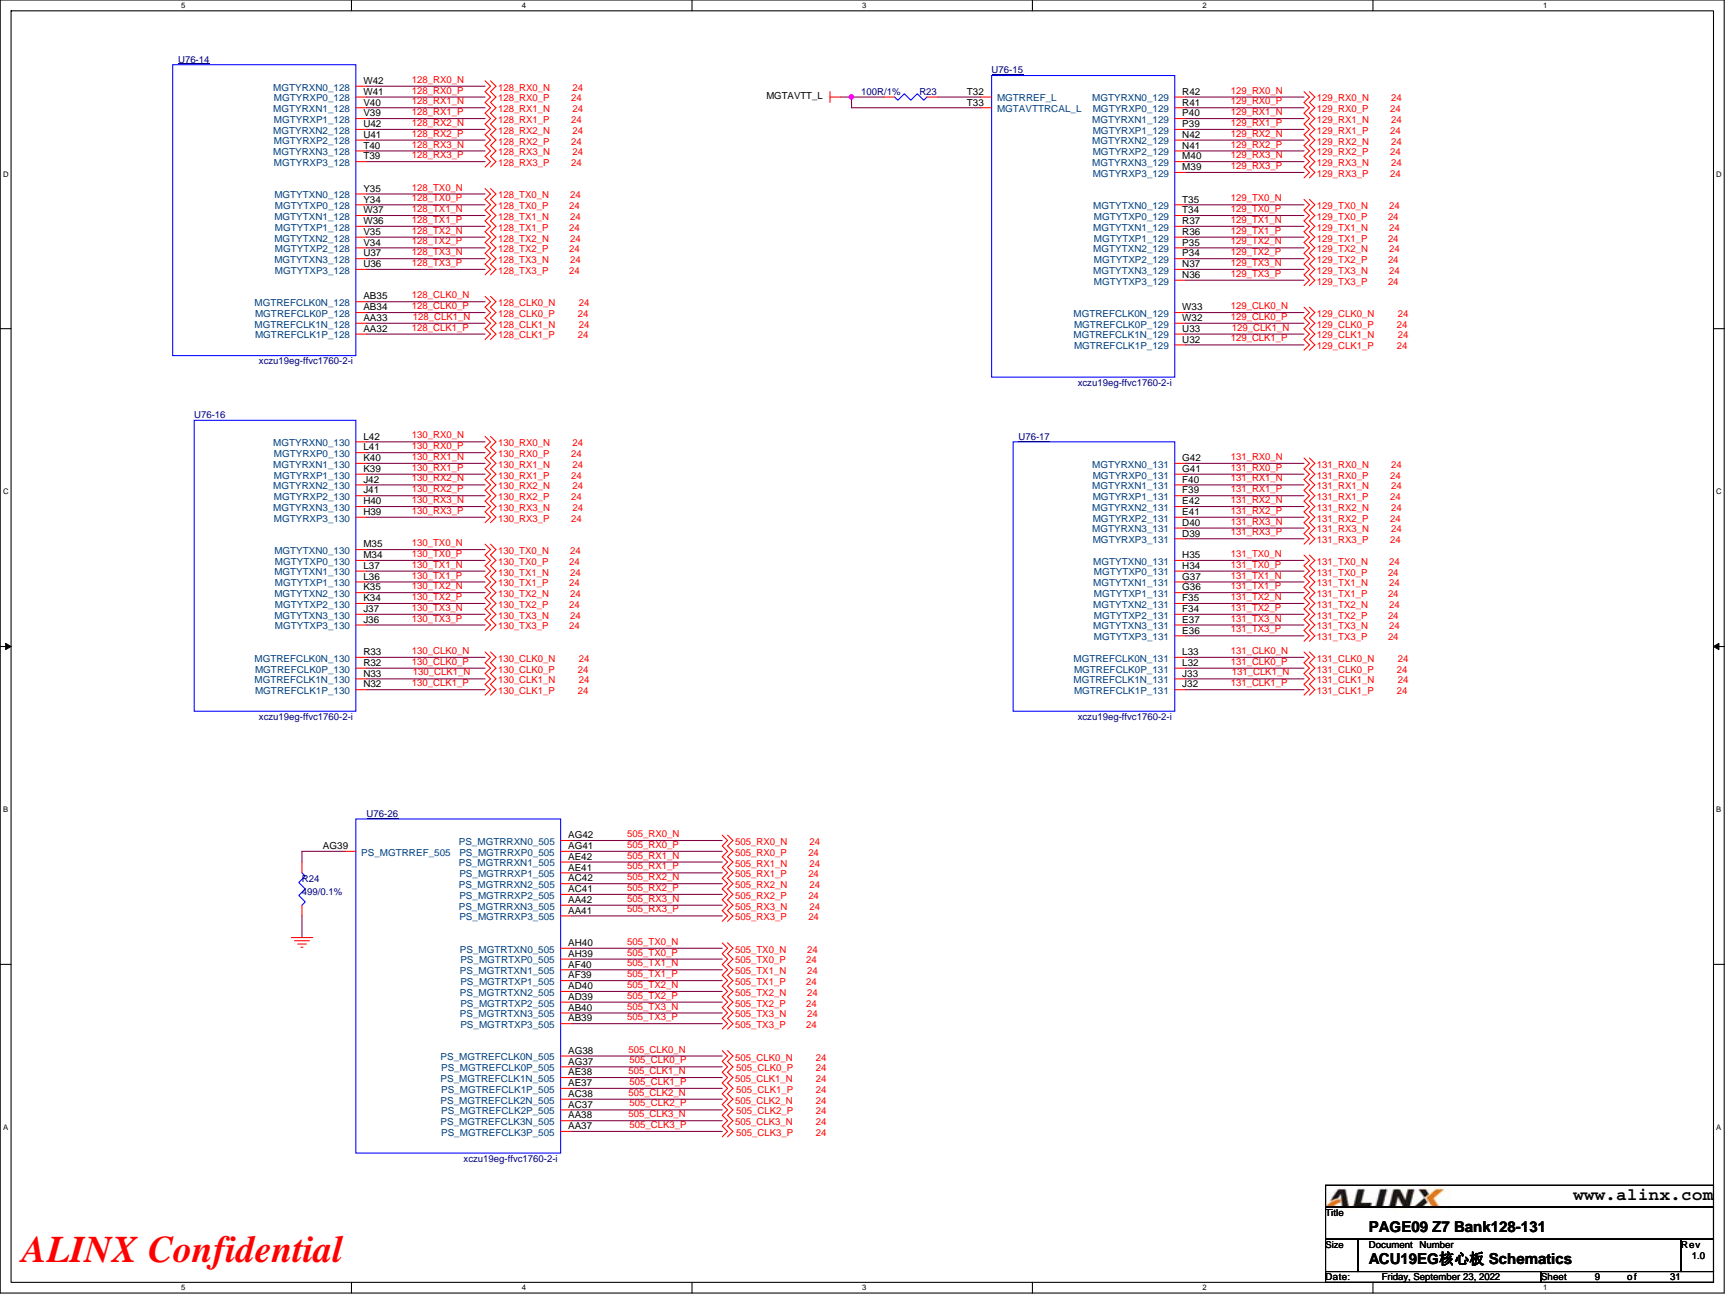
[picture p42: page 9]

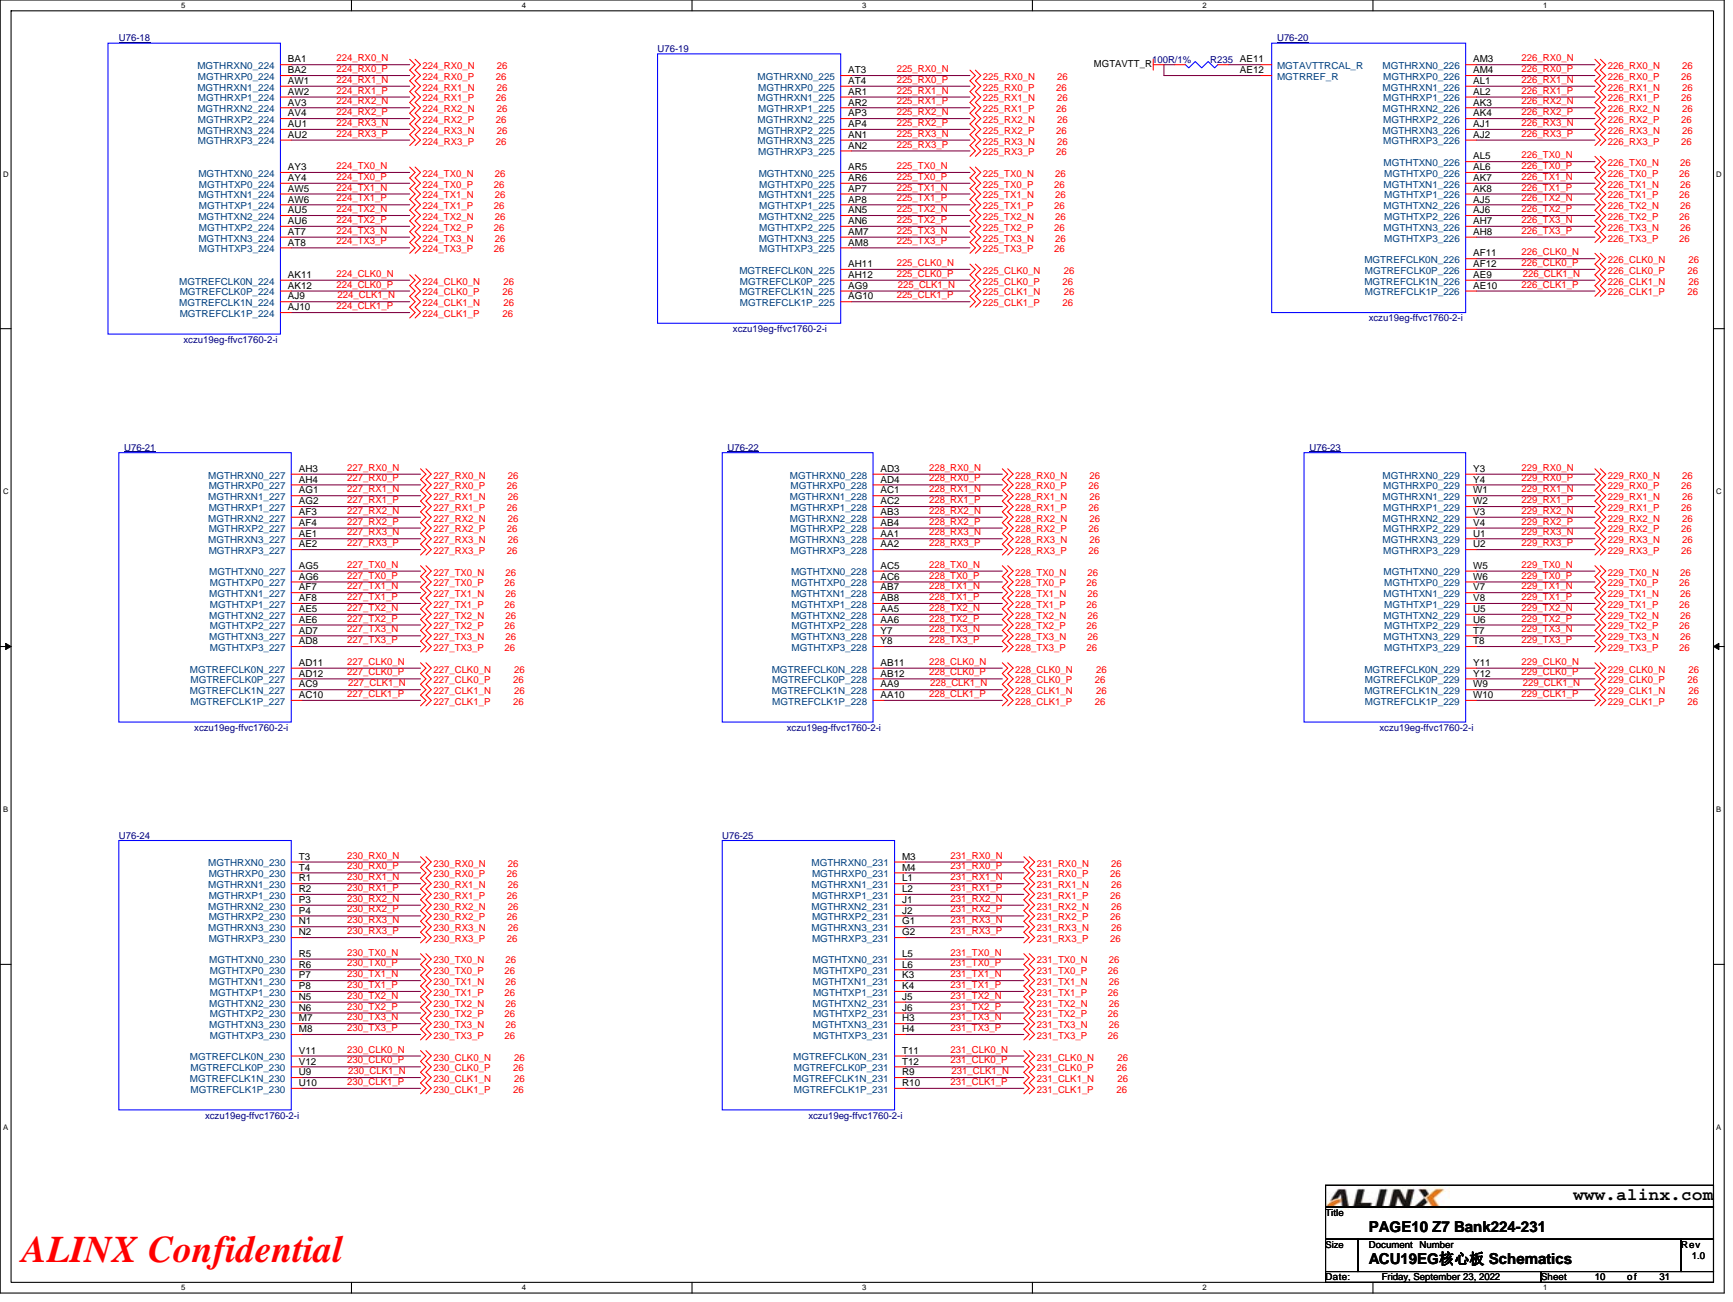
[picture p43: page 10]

# POWER ON: VCCINT/VCCINT_IO/VCCBRAM(+0.85V)->VCCAUX/VCCAUX_IO(+1.8V)->VCCO(+3.3V, +1.8V)

0.9V

POWER ON: VCC_PSINTFP/VCC_PSINTFP_DDR(+0.85V)->VPS_MGTRAVCC(+0.9V),VCC_PSDDR_PLL(+1.8V)->VPS_MGTRAVTT(+1.8V),VCCO_PSDDR() POWER ON: VCC_PSINTLP(+0.85V)->VCC_PSAUX(+1.8V),VCC_PSADC(+1.8V),VCC_PSPLL(+1.2V)->VCCO_PSIO(+1.8V)

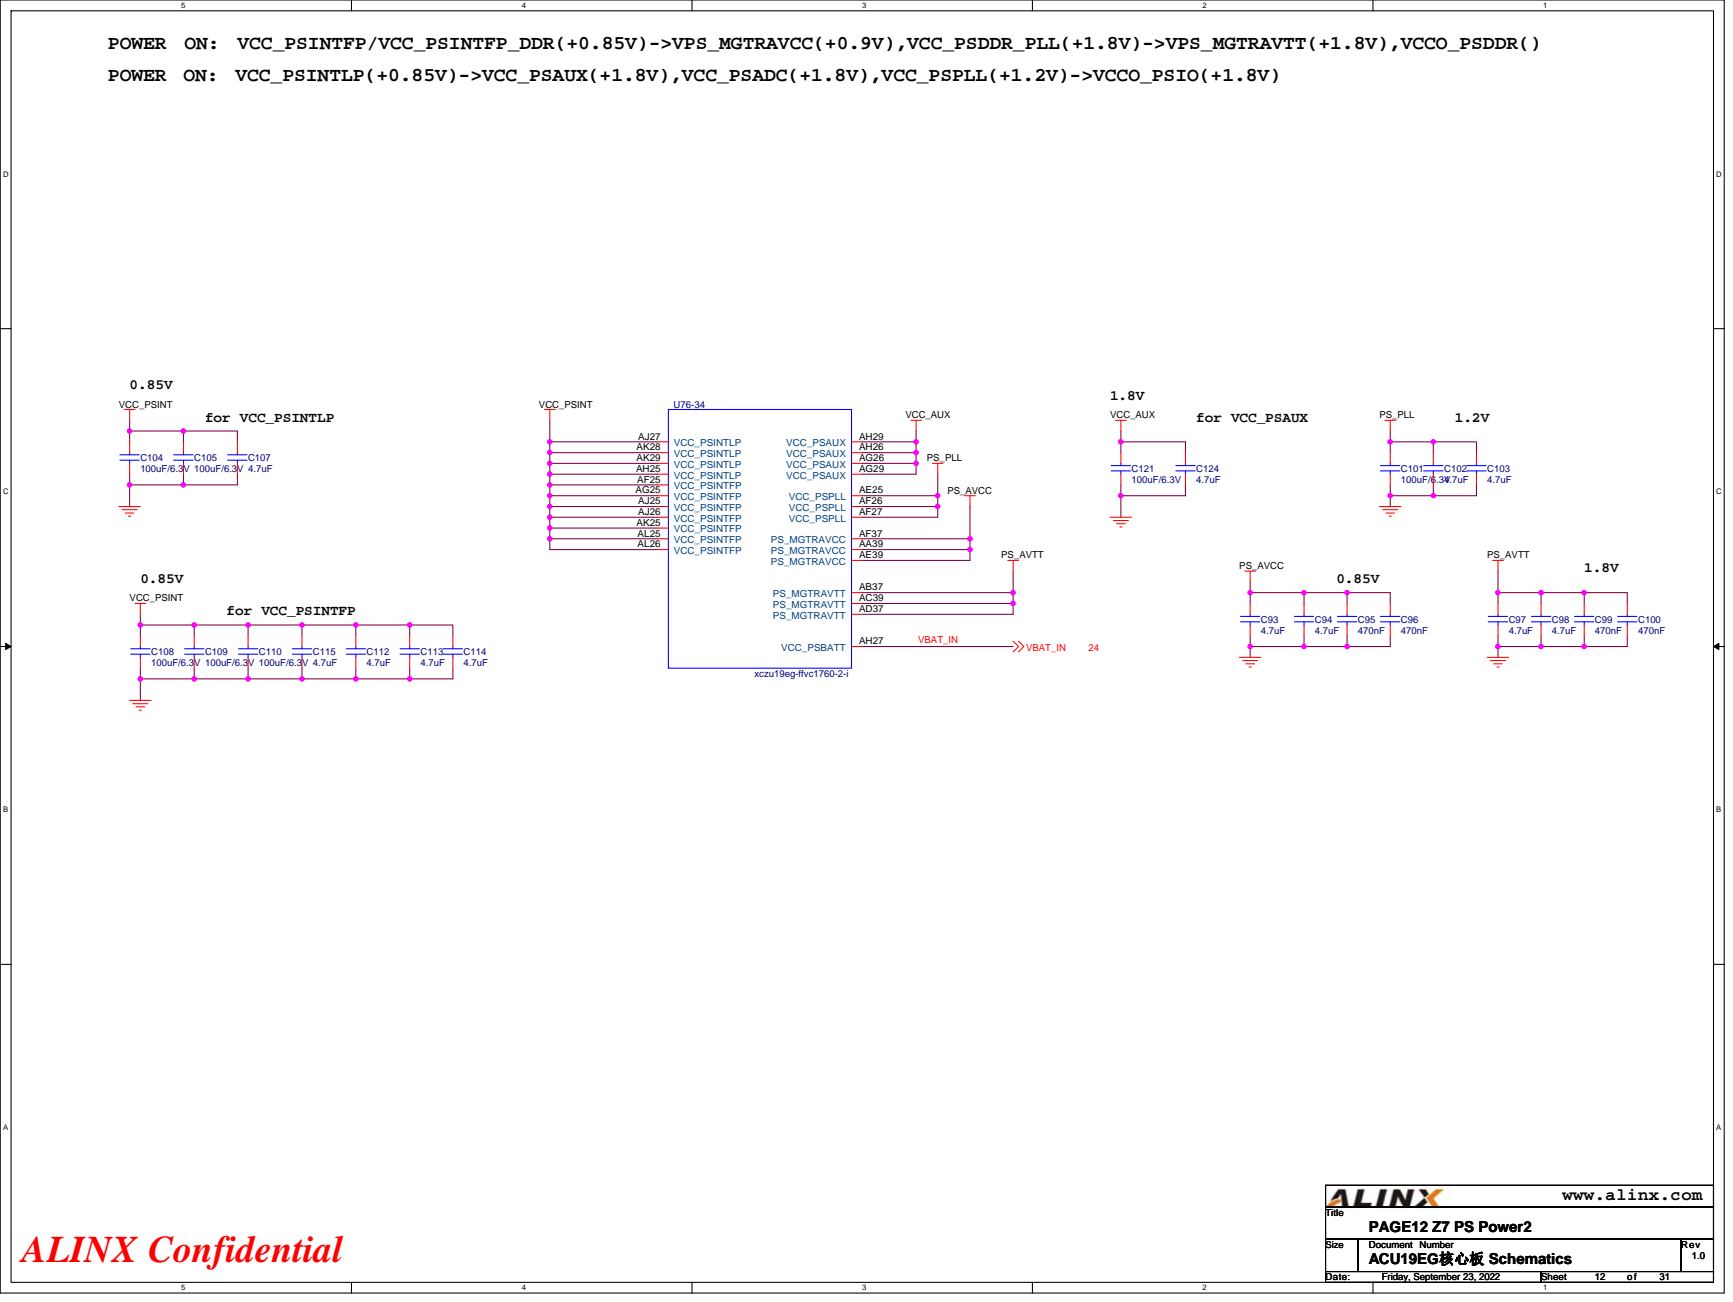
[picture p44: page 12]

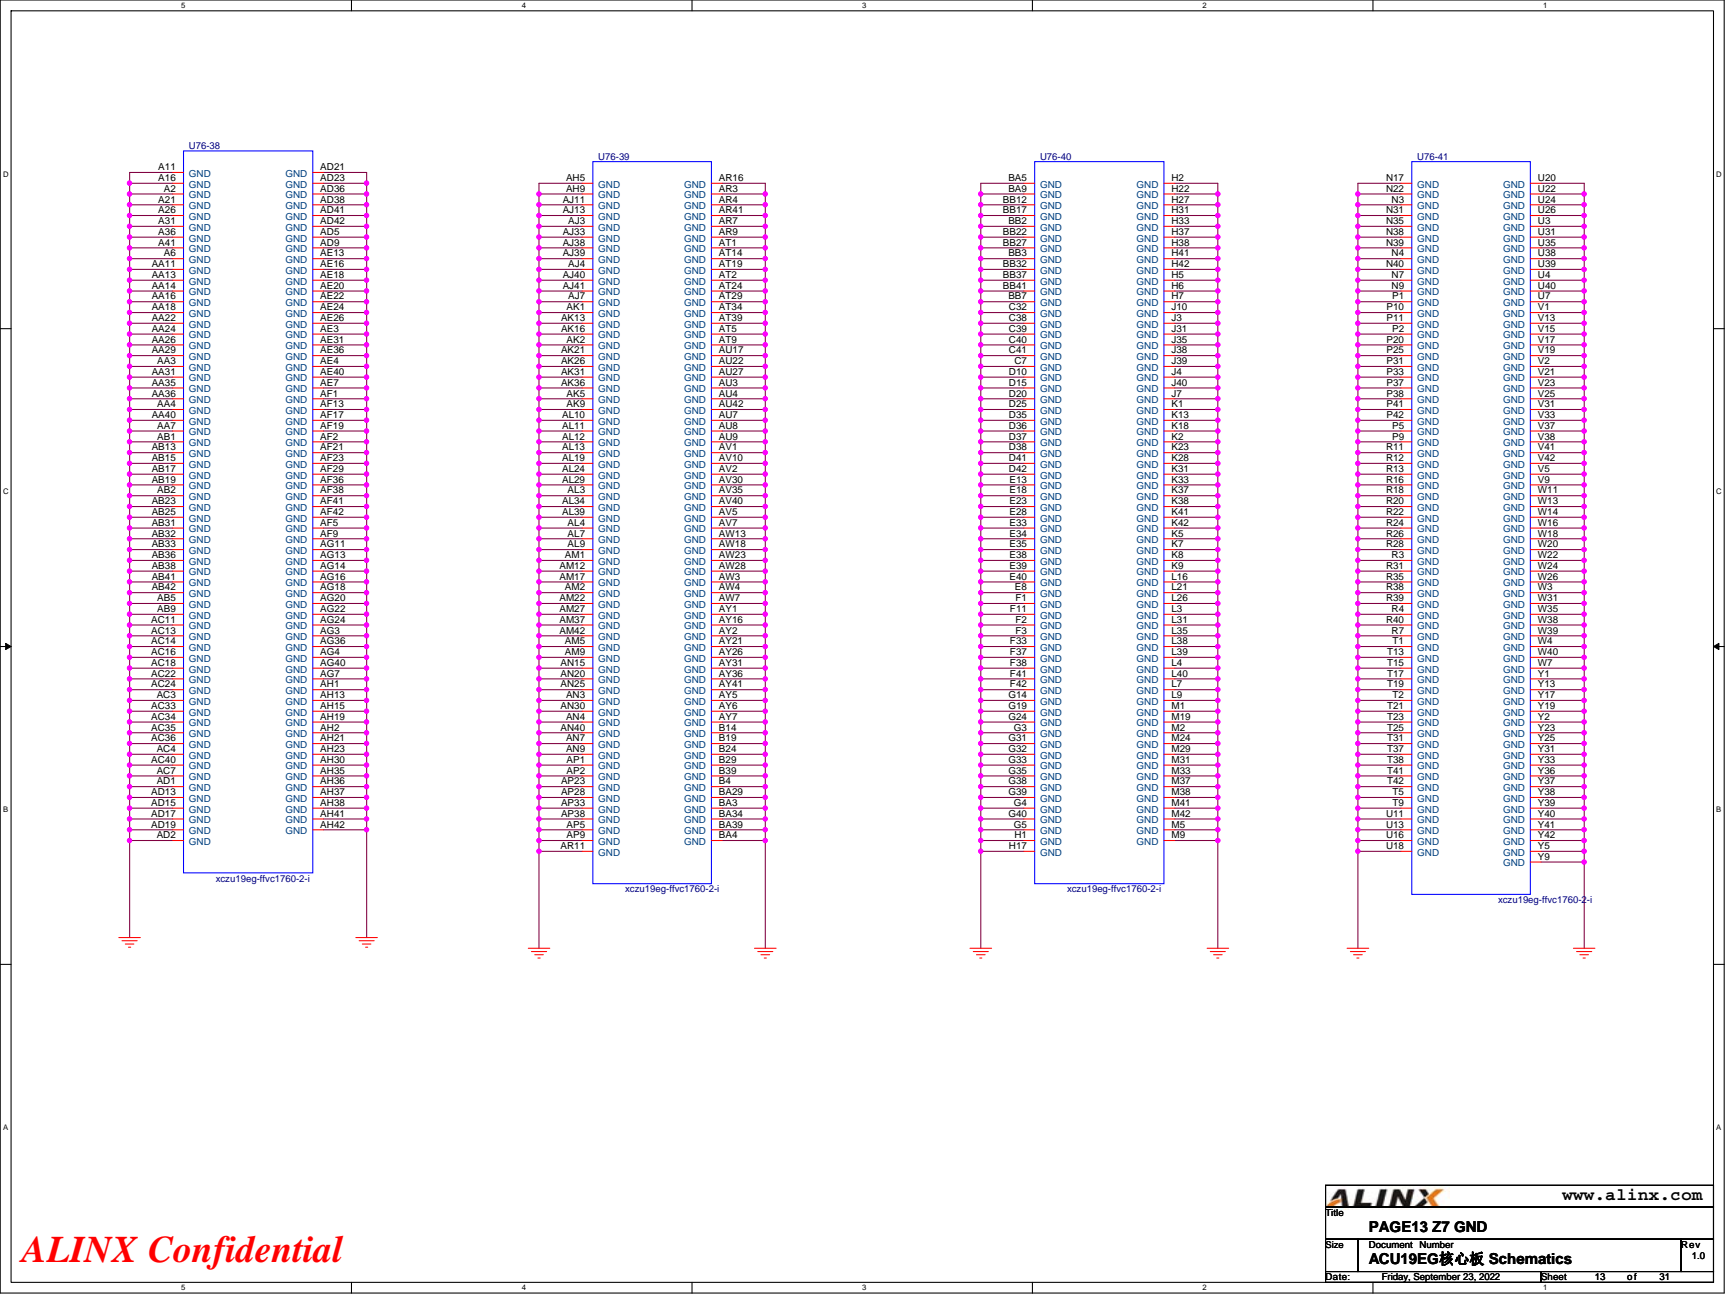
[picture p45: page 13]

1.2V

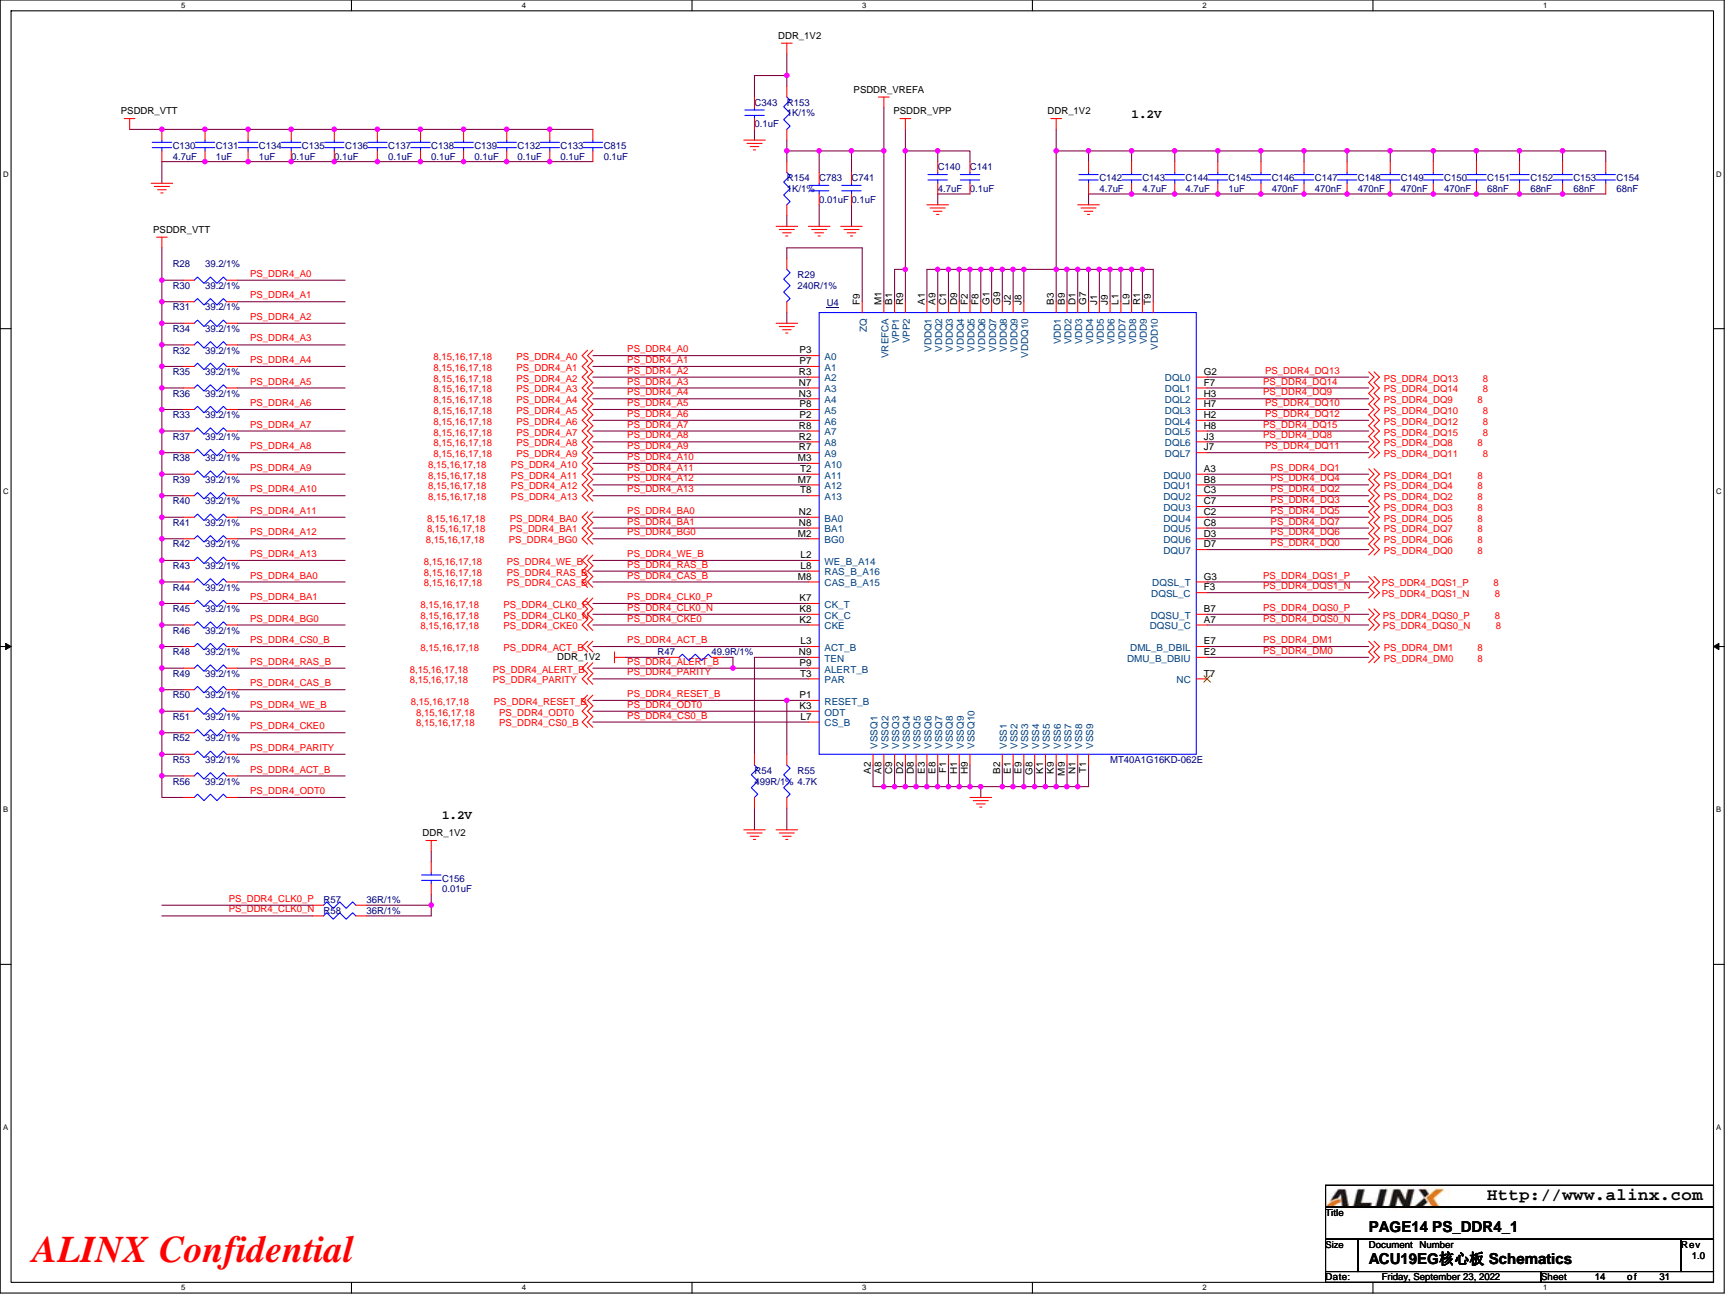
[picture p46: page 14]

Http://www.alinx.com

1.2V

Http://www.alinx.com

1.2V

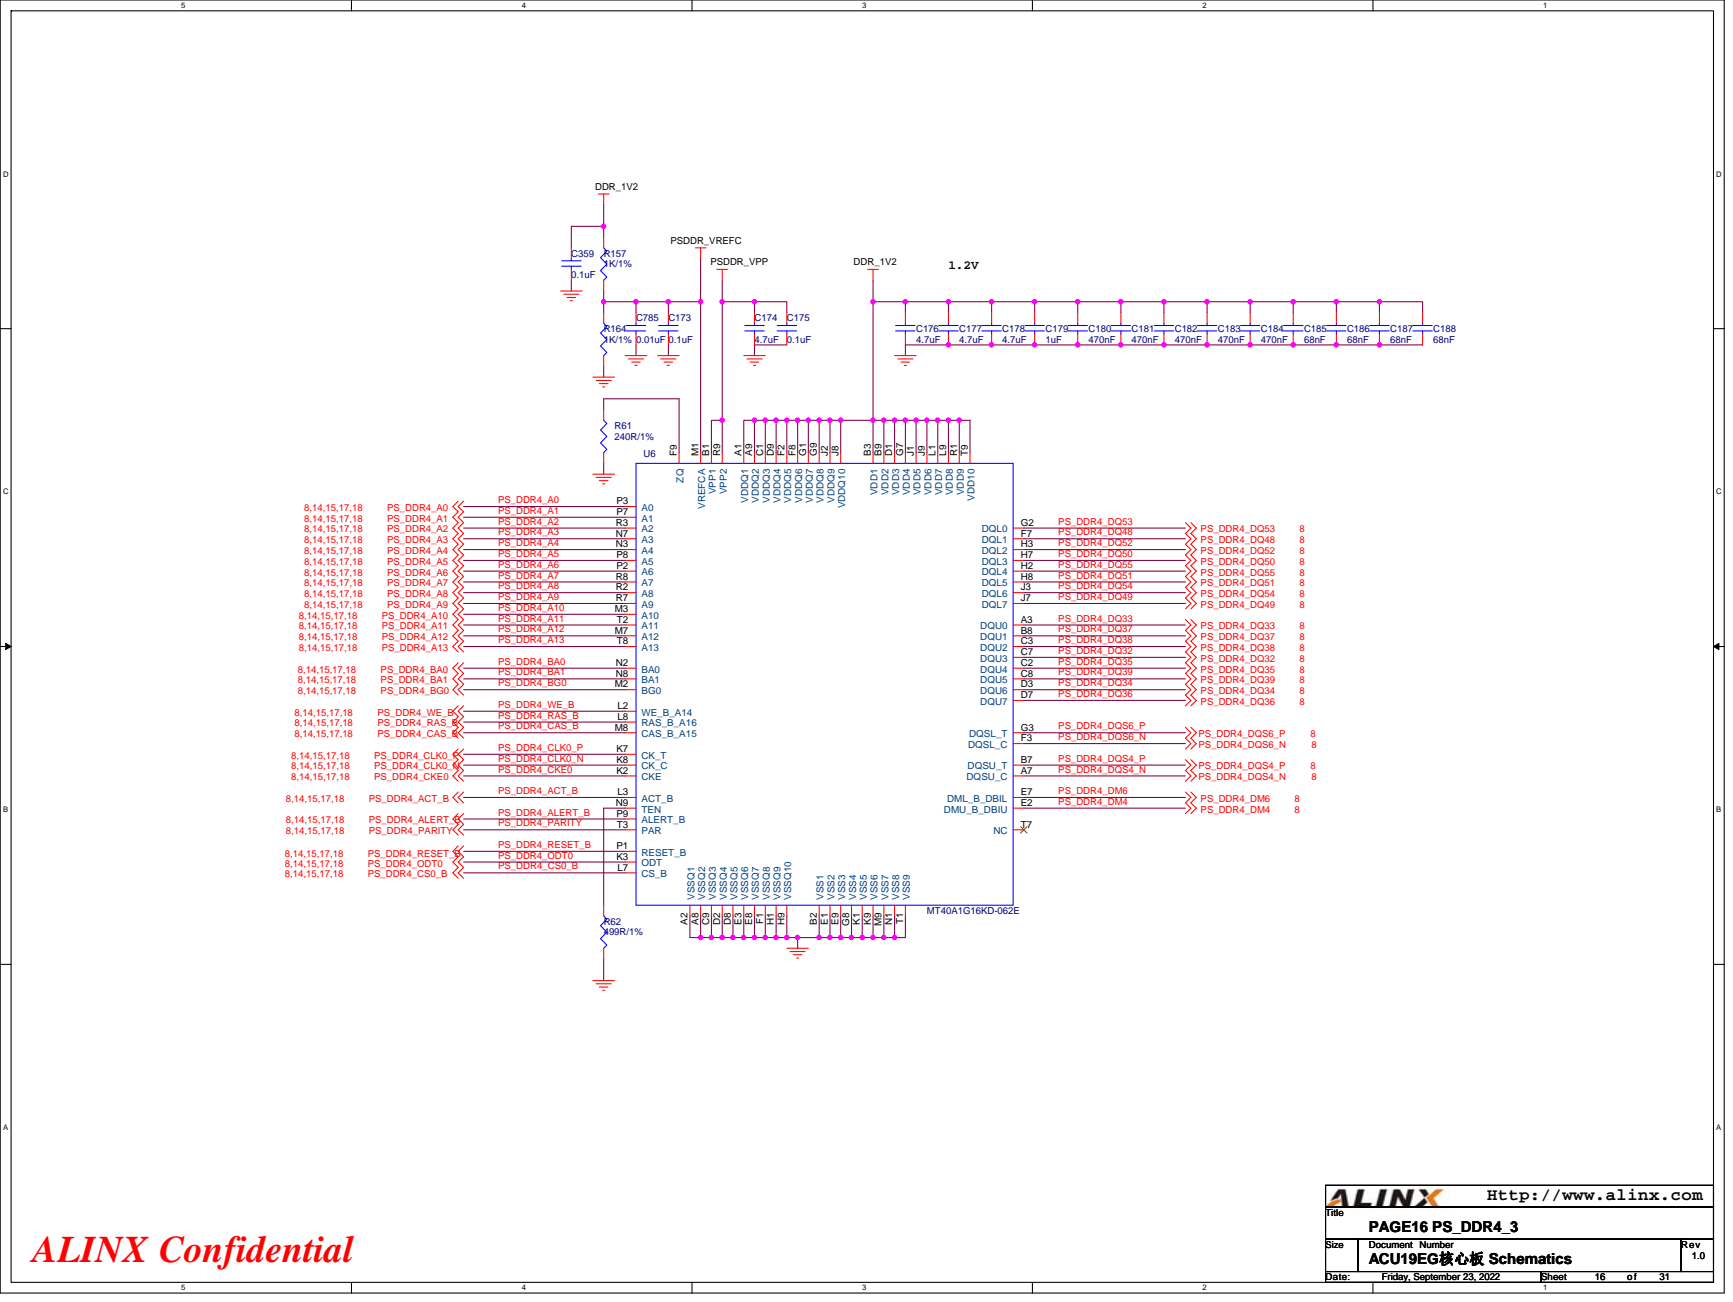
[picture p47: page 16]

Http://www.alinx.com

1.2V


Http://www.alinx.com

1.2V


Http://www.alinx.com




# MIO/SD/USB/ETH IO Voltage is 1.8V Stardard

131_CLK1_P 131_CLK1_N; 130_CLK1_P 130_CLK1_N; 129_CLK1_P 129_CLK1_N; 128_CLK1_P 128_CLK1_N; 131_CLK0_P 131_CLK0_N; 130_CLK0_P 130_CLK0_N; 129_CLK0_P 129_CLK0_N; 128_CLK0_P 128_CLK0_N; DP_HPD_MIO28; DP_AUX_IN_MIO30; DP_AUX_OUT_MIO27; 505_CLK0_N 505_CLK0_P; 505_CLK3_N 505_CLK3_P; 505_CLK2_N 505_CLK2_P; 505_CLK1_N 505_CLK1_P; DP_OE_MIO29; FPGA_TMS FPGA_TDI; PS_MODE3; PS_MODE0; PS_MODE1; PS_MODE2; FPGA_TDO FPGA_TCK; CAN0_TX CAN0_RX; CAN1_TX; CAN1_RX; POWER_SW; PS_MIO42 PS_MIO43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

Http://www.alinx.com

BANK64,65 is HP BANK, IO Voltage is under 1.8V | BANK66 67 is HP BANK, IO Voltage is under 1.8V

PAGE25 Connector2; Friday, September 23, 2022; AXK5A2137YG

Http://www.alinx.com

228_CLK0_N; 228_CLK1_P; 228_CLK0_P; 228_CLK1_N; 229_CLK0_N; 229_CLK1_P; 229_CLK0_P; 229_CLK1_N; 230_CLK0_N; 230_CLK1_P; 230_CLK0_P; 230_CLK1_N; 231_CLK0_N; 231_CLK1_P; 231_CLK0_P; 231_CLK1_N; 224_CLK1_P; 225_CLK1_P; 226_CLK1_P; 227_CLK1_P; 224_CLK1_N; 225_CLK1_N; 226_CLK1_N; 227_CLK1_N; 224_CLK0_P; 225_CLK0_P; 226_CLK0_P; 227_CLK0_P; 224_CLK0_N; 225_CLK0_N; 226_CLK0_N; 227_CLK0_N; PAGE26 Connector3; Friday, September 23, 2022; AXK5A2137YG

Http://www.alinx.com

BANK90,91,93,94 is HD BANK, IO Voltage is under 3.3V | BANK68 is HP BANK, IO Voltage is under 1.8V

VCCO_66; VCCO_68; VCCO_65; VCCO_67; VCCO_64; PAGE27 Connector4; Friday, September 23, 2022; AXK5A2137YG

Http://www.alinx.com

# GPO1-----BUCK2_PG GPO4-----BUCK4_PG


PMIC_3V3_BUCK1 | PVIN3 11

Vsw BG 4 | 5

PMIC_3V3_BUCK1 | PVINSWA1 32 | R90 9.31K /1%

VCC_AUX | PVINSWB1_B2 18

PSDDR_VPP | | LDOA1 9

VTT 47 | | 0.1uF

VREF 53

LDO5P0 56 | R99 11K/1%

PMIC_3V3_LDO | | LDO3P3 54

+0.85V 60A


AGND | AGND 7 DVDD 8

DGND 26 PGOOD 20

1.5A | 1.5A | 1.8V 0.85V

+0.9V 6A

+1.2V 6A


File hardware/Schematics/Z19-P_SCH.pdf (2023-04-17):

ALINX Confidential; Title; PAGE01 Block diagram

www.alinx.com

Size | Document Number Z19-P开发板 Schematics | Rev 1.0

Date: Monday, September 19, 2022 Monday, September 19, 2022 Monday, September 19, 2022 | Sheet 1 1 1 of 22 22 22

# MIO/SD/USB/ETH IO Voltage is 1.8V Stardard


130_CLK0_N | 33 | 34 | 130_CLK1_N

Http://www.alinx.com

# BANK64,65 is HP BANK, IO Voltage is under 1.8V

# BANK66 67 is HP BANK, IO Voltage is under 1.8V

FMC1_LA00_CC_N; FMC1_LA00_CC_P; FMC1_LA01_CC_N; FMC1_LA01_CC_P; FMC1_LA05_N; FMC1_LA05_P; FMC1_LA16_N; FMC1_LA16_P; FMC1_LA11_N; FMC1_LA11_P; FMC1_CLK1_N; FMC1_CLK1_P; FMC1_HB02_P; FMC1_HB02_N; FMC1_HB05_P; FMC1_HB05_N; FMC1_LA15_N; FMC1_LA15_P; FMC1_LA14_N; FMC1_LA14_P; FMC1_LA13_N; FMC1_LA13_P; FMC1_LA02_N; FMC1_LA02_P; FMC1_LA03_N; FMC1_LA03_P; FMC1_LA12_N; FMC1_LA12_P; FMC1_LA06_N; FMC1_LA06_P; FMC1_LA09_N; FMC1_LA09_P; FMC1_LA07_N; FMC1_LA07_P; FMC1_LA08_N; FMC1_LA08_P; FMC1_LA10_N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

Http://www.alinx.com


88 | 230_CLK0_P
90 | 231_RX0_N 231_RX0_P 231_RX1_N 231_RX1_P 231_RX2_N 231_RX2_P 231_RX3_N 231_RX3_P

231_CLK1_P | 117 | 118 | 231_CLK0_P

Http://www.alinx.com

BANK90,91,93,94 is HD BANK, IO Voltage is under 3.3V | BANK68 is HP BANK, IO Voltage is under 1.8V


Http://www.alinx.com

# MODE[3:0]

0000 | PS JTAG | PS JTAG Interface


0001 | Quad_SPI(24b) | 24-Bit addresssing(QSPI24)
0010 | Quad_SPI(32b) | 32-Bit addresssing(QSPI32)
0011 | SD0(2.0) | SD2.0
0100 | NAND | Requires 8-bit data bus width
0101 | SD1(2.0) | SD2.0
0110 0111 | eMMC(1.8V) USB0(2.0) | eMMC version 4.5 at 1.8V USB 2.0 only

# DP CLOCK = 27Mhz

# USB CLOCK = 26Mhz


R31 NC | INPUT2 19

INPUT3 20 | PL_REF_CLK_R


Http://www.alinx.com


Http://www.alinx.com

1.2V


TRD1- P7

TRD1+ P4

TRD0- P3

TRD0+ P2

Http://www.alinx.com


Http://www.alinx.com


Http://www.alinx.com

# PS UART PORT


Http://www.alinx.com

# SD Card Connector


Http://www.alinx.com


Http://www.alinx.com


Http://www.alinx.com

FMC1_DP1_M2C_N; FMC1_DP1_M2C_P; FMC1_DP2_M2C_N; FMC1_DP2_M2C_P; FMC1_DP3_M2C_N; FMC1_DP3_M2C_P; FMC1_DP4_M2C_P FMC1_DP4_M2C_N; FMC1_DP5_M2C_N; FMC1_DP5_M2C_P; FMC1_DP6_M2C_N; FMC1_DP6_M2C_P; FMC1_DP7_M2C_N; FMC1_DP7_M2C_P; FMC1_DP1_C2M_P FMC1_DP1_C2M_N; FMC1_DP2_C2M_P FMC1_DP2_C2M_N; FMC1_DP3_C2M_P FMC1_DP3_C2M_N; FMC1_DP4_C2M_P FMC1_DP4_C2M_N; FMC1_DP5_C2M_P FMC1_DP5_C2M_N; FMC1_DP6_C2M_P FMC1_DP6_C2M_N; FMC1_DP7_C2M_P FMC1_DP7_C2M_N; FMC1_GBTCLK1_M2C_P FMC1_GBTCLK1_M2C_N; FMC1_DP4_M2C_P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

Http://www.alinx.com


Http://www.alinx.com


Http://www.alinx.com

FMC2_DP1_M2C_N; FMC2_DP1_M2C_P; FMC2_DP2_M2C_N; FMC2_DP2_M2C_P; FMC2_DP3_M2C_N; FMC2_DP3_M2C_P; FMC2_DP4_M2C_P FMC2_DP4_M2C_N; FMC2_DP5_M2C_N; FMC2_DP5_M2C_P; FMC2_DP6_M2C_P; FMC2_DP7_M2C_N; FMC2_DP7_M2C_P; FMC2_DP1_C2M_P FMC2_DP1_C2M_N; FMC2_DP2_C2M_P FMC2_DP2_C2M_N; FMC2_DP3_C2M_P FMC2_DP3_C2M_N; FMC2_DP4_C2M_P FMC2_DP4_C2M_N; FMC2_DP5_C2M_P FMC2_DP5_C2M_N; FMC2_DP6_C2M_P FMC2_DP6_C2M_N; FMC2_DP7_C2M_P FMC2_DP7_C2M_N; FMC2_DP4_M2C_P; FMC2_DP4_M2C_N; FMC2_DP6_M2C_N; FMC2_DP1_C2M_P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

GND A17 | FMC2_DP6_M2C_N
DP5_M2C_P A18 DP5_M2C_N A19 GND A20 | FMC2_GBTCLK1_M2C_P

GND A21 DP1_C2M_P A22 DP1_C2M_N A23 GND A24 GND A25 | FMC2_GBTCLK1_M2C_N

Http://www.alinx.com

# PCIE X8 Socket


Http://www.alinx.com

# 12V/3A AC Adapter

# FAN


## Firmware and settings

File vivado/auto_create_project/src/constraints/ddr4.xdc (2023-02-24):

set_property PACKAGE_PIN   M21   [ get_ports "ddr4_adr[0]" ]
set_property PACKAGE_PIN   N21   [ get_ports "ddr4_adr[1]" ]
set_property PACKAGE_PIN   E20   [ get_ports "ddr4_adr[2]" ]
set_property PACKAGE_PIN   P21   [ get_ports "ddr4_adr[3]" ]
set_property PACKAGE_PIN   E21   [ get_ports "ddr4_adr[4]" ]
set_property PACKAGE_PIN   E19   [ get_ports "ddr4_adr[5]" ]
set_property PACKAGE_PIN   M22   [ get_ports "ddr4_adr[6]" ]
set_property PACKAGE_PIN   J19   [ get_ports "ddr4_adr[7]" ]
set_property PACKAGE_PIN   J21   [ get_ports "ddr4_adr[8]" ]
set_property PACKAGE_PIN   F20   [ get_ports "ddr4_adr[9]" ]
set_property PACKAGE_PIN   L20   [ get_ports "ddr4_adr[10]" ]
set_property PACKAGE_PIN   M20   [ get_ports "ddr4_adr[11]" ]
set_property PACKAGE_PIN   N20   [ get_ports "ddr4_adr[12]" ]
set_property PACKAGE_PIN   K19   [ get_ports "ddr4_adr[13]" ]
set_property PACKAGE_PIN   J22   [ get_ports "ddr4_adr[14]" ]
set_property PACKAGE_PIN   H19  [ get_ports "ddr4_adr[15]" ]
set_property PACKAGE_PIN   H20   [ get_ports "ddr4_adr[16]" ]

set_property PACKAGE_PIN K22 [ get_ports "ddr4_ba[0]" ]
set_property PACKAGE_PIN F19 [ get_ports "ddr4_ba[1]" ]
set_property PACKAGE_PIN F22 [ get_ports "ddr4_bg[0]" ]


set_property PACKAGE_PIN G22 [ get_ports "ddr4_ck_t[0]" ]
set_property PACKAGE_PIN G21 [ get_ports "ddr4_ck_c[0]" ]
set_property PACKAGE_PIN D21 [ get_ports "ddr4_cke[0]" ]

set_property PACKAGE_PIN K20 [ get_ports "ddr4_act_n" ]

set_property PACKAGE_PIN F23 [ get_ports "ddr4_reset_n" ]
set_property PACKAGE_PIN K21 [ get_ports "ddr4_odt[0]" ]
set_property PACKAGE_PIN N19 [ get_ports "ddr4_cs_n[0]" ]

set_property PACKAGE_PIN G23 [ get_ports "ddr4_dqs_c[0]" ]
set_property PACKAGE_PIN H23 [ get_ports "ddr4_dqs_t[0]" ]
set_property PACKAGE_PIN K24 [ get_ports "ddr4_dqs_c[1]" ]
set_property PACKAGE_PIN L24 [ get_ports "ddr4_dqs_t[1]" ]
set_property PACKAGE_PIN B26 [ get_ports "ddr4_dqs_c[2]" ]
set_property PACKAGE_PIN B25 [ get_ports "ddr4_dqs_t[2]" ]
set_property PACKAGE_PIN E27 [ get_ports "ddr4_dqs_c[3]" ]
set_property PACKAGE_PIN E26 [ get_ports "ddr4_dqs_t[3]" ]
set_property PACKAGE_PIN A32 [ get_ports "ddr4_dqs_c[4]" ]
set_property PACKAGE_PIN B31 [ get_ports "ddr4_dqs_t[4]" ]
set_property PACKAGE_PIN F30 [ get_ports "ddr4_dqs_c[5]" ]
set_property PACKAGE_PIN G30 [ get_ports "ddr4_dqs_t[5]" ]
set_property PACKAGE_PIN A40 [ get_ports "ddr4_dqs_c[6]" ]
set_property PACKAGE_PIN A39 [ get_ports "ddr4_dqs_t[6]" ]
set_property PACKAGE_PIN C34 [ get_ports "ddr4_dqs_c[7]" ]
set_property PACKAGE_PIN D34 [ get_ports "ddr4_dqs_t[7]" ]


set_property PACKAGE_PIN K27 [ get_ports "ddr4_dm_n[0]" ]
set_property PACKAGE_PIN P26 [ get_ports "ddr4_dm_n[1]" ]
set_property PACKAGE_PIN C28 [ get_ports "ddr4_dm_n[2]" ]
set_property PACKAGE_PIN G26 [ get_ports "ddr4_dm_n[3]" ]
set_property PACKAGE_PIN E29 [ get_ports "ddr4_dm_n[4]" ]
set_property PACKAGE_PIN K29 [ get_ports "ddr4_dm_n[5]" ]
set_property PACKAGE_PIN C36 [ get_ports "ddr4_dm_n[6]" ]
set_property PACKAGE_PIN E32 [ get_ports "ddr4_dm_n[7]" ]
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

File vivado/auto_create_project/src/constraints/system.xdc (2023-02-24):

set_property BITSTREAM.GENERAL.COMPRESS TRUE [current_design] 

set_property IOSTANDARD DIFF_SSTL12 [get_ports sys_clk_p]
set_property PACKAGE_PIN H21 [get_ports sys_clk_p]
create_clock -period 5.000 -name sys_clk_clk_p -waveform {0.000 2.500} [get_ports sys_clk_p]

#pl led
set_property PACKAGE_PIN E10 [get_ports {pl_led_tri_o[0]}]
set_property PACKAGE_PIN E11 [get_ports {pl_led_tri_o[1]}]
set_property IOSTANDARD LVCMOS33 [get_ports {pl_led_tri_o[*]}]

set_property PACKAGE_PIN M11 [get_ports {uart_rxd}]
set_property IOSTANDARD LVCMOS18 [get_ports {uart_rxd}]

set_property PACKAGE_PIN M12 [get_ports {uart_txd}]
set_property IOSTANDARD LVCMOS18 [get_ports {uart_txd}]

set_property PACKAGE_PIN F4 [get_ports {fan_tri_o[0]}]
set_property IOSTANDARD LVCMOS33 [get_ports {fan_tri_o[0]}]

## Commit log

2023-03-23 add linux
    [bsp.cfg, devtool-fragment.cfg]
2023-04-14 add hardware
    [ACU19EG.stp, ACU19EG_size_structure.dxf, Z19-P.stp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]
